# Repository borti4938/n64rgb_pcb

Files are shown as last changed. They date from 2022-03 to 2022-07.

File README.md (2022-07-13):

N64RGBv2.1 (PCB)
---

This repository contains all you need files to build your own DIY N64RGBv2.1 board.
Firmware is supplied in another repository.

Please don't ask me for selling a modding.
I either sell some prototypes on some forums marketplaces (which is very unlikely) or I don't have any of the boards.
This is a complete DIY modding project.
Everybody is on his own here.

**WARNING:**
This is an advanced DIY project if you do everything on your own. You need decent soldering skills.
The CPLD and the video DAC have 0.5mm fine pitched pins.
On the board there are some SMD1206 resistor and ferrite bead arrays.
However, there are some awesome shops out there selling the boards for a great price.

## Table of Contents

- [Checklist](https://github.com/borti4938/n64rgb_pcb#checklist-how-to-build-the-project)
- [Assembly](https://github.com/borti4938/n64rgb_pcb#assembly)
- [Installation](https://github.com/borti4938/n64rgb_pcb#installation)
  - [1. Open the Console](https://github.com/borti4938/n64rgb_pcb#1-open-the-console)
  - [2. Optional Steps](https://github.com/borti4938/n64rgb_pcb#2-optional-steps)
  - [3. Solder Work](https://github.com/borti4938/n64rgb_pcb#3-solder-work)
  - [4. Mount the N64 Advanced Modding PCB](https://github.com/borti4938/n64rgb_pcb#4-mount-the-n64-advanced-modding-pcb)
  - [5. Finish the Work](https://github.com/borti4938/n64rgb_pcb#5-finish-the-work)
- [Jumper Setup](https://github.com/borti4938/n64rgb_pcb#jumper-setup)
- [Cable Setup](https://github.com/borti4938/n64rgb_pcb#cable-setup)

## Checklist: How to build the project

- Use PCB files (either [KiCad-PCB design file](./n64rgbv2.1.kicad_pcb) or [Gerber files](./Gerber/)) to order your own PCB or simply use the [shared project(s) on OSHPark](https://oshpark.com/profiles/borti4938)
- If you paln to use solder paste, do not forget to order a stencil for top and bottom, too
- Source the components you need, e.g. from Mouser or Digikey.  
  The BOM is available in [here](./doc/BOM_n64rgbv2.1.xlsx).
- Wait for everything to arrive
- Assemble your PCB if you haven't use a PCBA service
- Set all jumpers
- Flash the firmware ([firmware releases](https://github.com/borti4938/n64rgb_fw/releases)) to the CPLD after installation (e.g. using an Altera USB Blaster)
  - Use the POF programming file named n64rgbv2\_1\__cpld-device_.pof
  - Using the intelFPGA programmer, JTAG chain is initialized by loading POF file
  - N64 needs to be powered for flashing
  - Power cycle the N64 after flashing
- If you want to go for a clean installation with custom made flexible PCBs, just visit the repository for add ons ([Flex PCB for the digital video interface](https://github.com/borti4938/n64rgb_project_misc/RCP2N64RGB), [Flex PCB for the analog video output](https://github.com/borti4938/n64rgb_project_misc/N64RGB2MoutFilter)

## Assembly

If you have all components available, you can start assembly your board.
The documentation provides assembly sheets ([top](./doc/n64rgb2.1_assembly_sheet_top.pdf) and [bottom](./doc/1_assembly_sheet_bot.pdf), which you can print out.
Together with the [BOM](./doc/BOM_n64rgbv2.1.xlsx) it is just a matter of time and effort to assembly everything.
Alternatively you can also use the [interactive BOM](./doc/ibom.html).

Please note that the assembly (and component sourcing) depends on which kind of CPLD family you use.
Supported are Max II and Max V CLPDs.
- If you use a Max II CPLD, you must use FB3 and leave U4, C41 and C42 unpopulated.
- If you use a Max V CPLD, you must use U4, C41 and C42 and leave FB3 unpopulated.

If you populate J3, which is the JTAG connector, please short the pins such that they are flush at the bottom side.
This reduces the risk to short on of these pins with the heat sink (where the PCB will be mounted).

Using non-clean flux (rosin based) is obviously recommended.
Even though it is "non-clean" I recommend cleaning everything afterwards (just for the visual finish).

Please double check everything for shorts once you finished your work.
Very important is that the power supply trace do not short to GND.
- 3.3V against GND (e.g. at C1 and at C52)
- 1.8V against GND (e.g. at C42)
- 5V against GND (e.g. at C4)

## Installation

Note that installation pictures partially show the N64Advanced board.
Pad design and installation is equivalent.

### 1. Open the console

- Remove Jumper Pak / Expansion Pak
- Remove screws from bottom side of the console  
(needs a 4.5mm gamebit tool)
- Lift top housing
- remove inner screws as marked  
(very last consoles made the heat sink design changed slightly)
- pull out the mainboard
- remove heat sink and RF shield
- **Hint** Now you have the chance to clean up your N64 shell

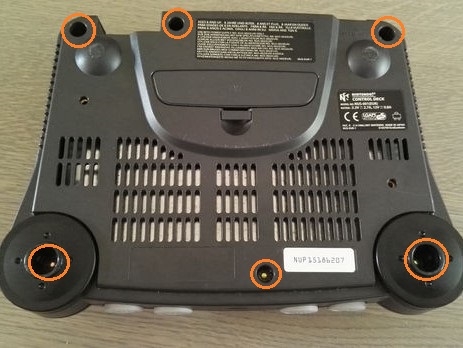
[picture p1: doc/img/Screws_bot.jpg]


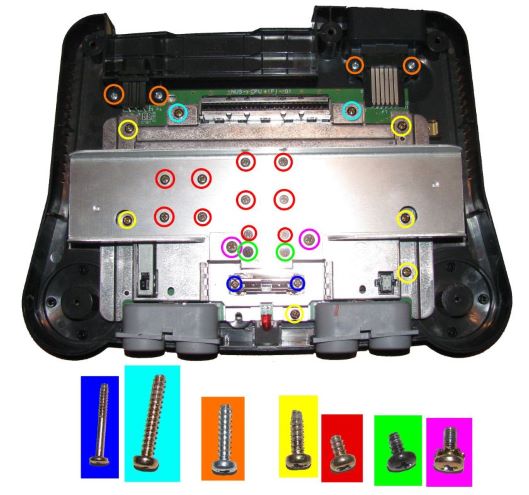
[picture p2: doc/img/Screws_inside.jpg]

(image by Zerberus (circuit-board.de user))

### 2. Optional Steps

#### 2.1 Preparation of Top RF Shield

This step is optional.
It helps a) to reduce mechanical stress on the flex cable (if used) and b) ensures maximal distance between digital signals (installation wires or flex cable) and analog signals (MultiOut).

- Locate the tap in the RF shield next to the cartridge slot at the side of the MultiOut.  
(this is the place where the installation wires / flex cable will be routed through)
- option 1: bend the tap away

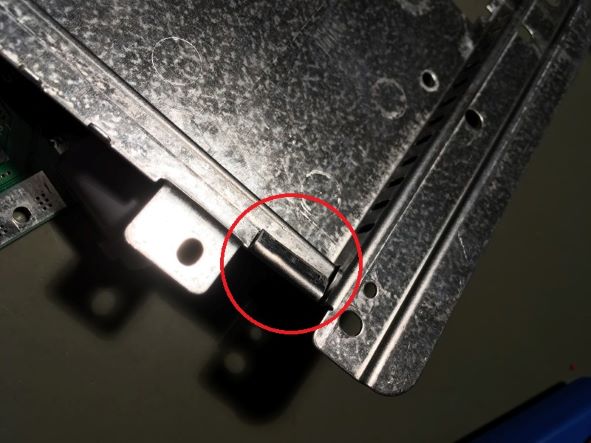
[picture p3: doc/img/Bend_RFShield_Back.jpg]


- option 2: simply cut the tab incl. the small piece up to the step in the RF shield

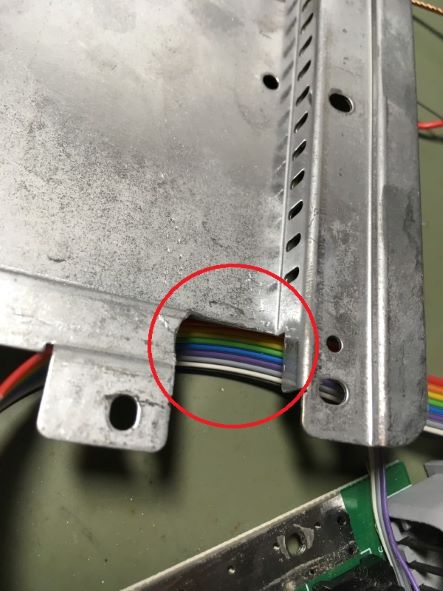
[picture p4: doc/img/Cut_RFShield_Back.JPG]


##### Some explanation on this optional step

Later, the data lines as well as the clock will be routed close to the MultiOut.
The distance between both is a crucial issue as your wires act as interferer.
Hence, having the tap bended might be ok, but it is better to cut some piece of the RF shield away to further increase the distance between MultiOut and data lines

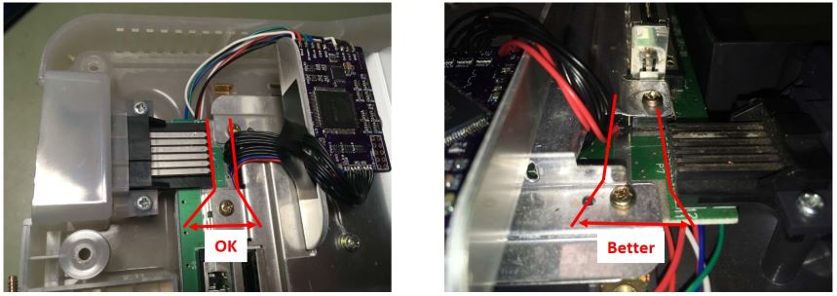
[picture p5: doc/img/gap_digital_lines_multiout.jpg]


#### GND insulation on the MultiOut

To have a better return path for the digital video lines defined, you may insulate GND from the MultiOut.
This step is only recommended if you have a noisy picture.
It comes with the drawback that a) you have a lot of more effort during installation and b) having a longer return path for the analog audio output as well as for S-Video and Composite Video as GND is later routed over the modding board.

- de-solder the MultiOut connector
- drill out the GND pads
- insulare the drills (e.g. with varnish (flex cable or wire install) or small shrink tubes (only wire installation))
- solder MultiOut back into place

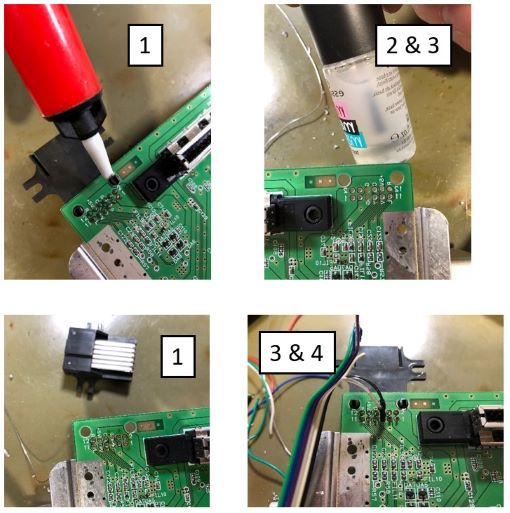
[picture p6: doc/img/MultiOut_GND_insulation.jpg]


### 3. Solder Work

You have the options to either install everything with casual installation wires or using flex cables.
This is just a trade-off between personal installation effort and price.
Personally, I recommend using the flex cable.

Sections 3.1 and 3.2 assume that you want to use the controller functions, so controller 1 will be connected.
However, this is optional, yet at the flex install the controller pad of the flex cable must not be left open!
Please also note section 3.3, where the installation of mechanical switches is described.

#### 3.1 Using the Flex Cable 

To use this option, you have to have the flex cables as shown at hand.
Note that the picture shows older prototype version.

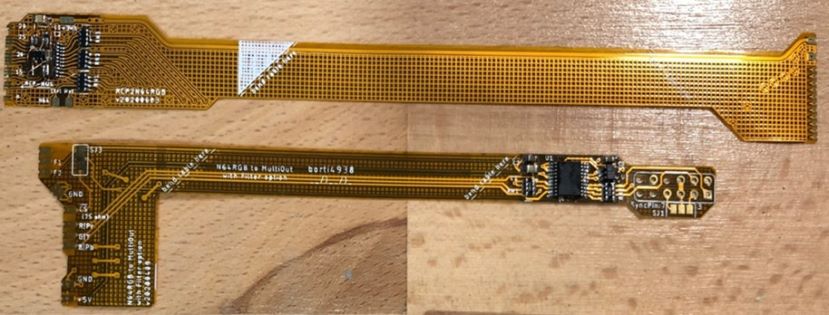
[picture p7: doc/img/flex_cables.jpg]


##### 3.1.1 Digital inputs

Start with the digital side:
- Solder the RCP connector side to the RCP-NUS as shown
  - first pin bottom – 8
  - last pin to – 28
- Connect 3.3V to the flex, e.g. taken from C141
- Connect Ctrl. and reset
  - reset from PIF-NUS pin 27
  - Controller from PIF-NUS pin 16  
  (Make sure that PIF-NUS pin 16 is connected to the middle pin of controller port 1, otherwise search for a suitable connection point)
- bend the flex as marked in a way such that you do not see the shaded area anymore.  
The flex will be routed over the MultiOut.

**Note**: when using the flex of version earlier than _v2022xxyy_ you need to cut the RF shield near the MultiOut as shown in 2.1

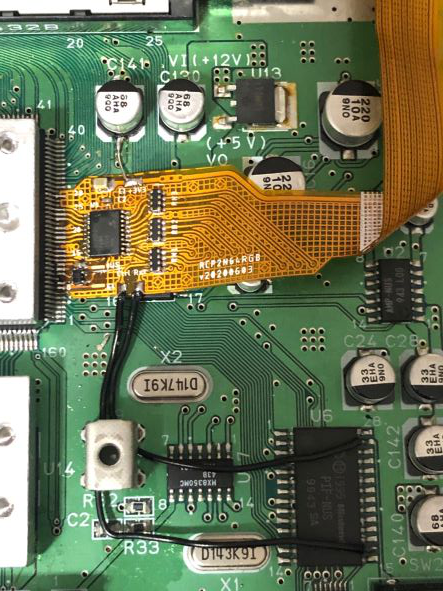
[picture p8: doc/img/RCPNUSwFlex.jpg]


##### 3.1.2 Analog outputs

Next up is the analog video flex which will be connected to the MultiOut.
Before you start here, make yourself clear where you want to route sync to.
This depends on whether you want to use sync on luma or sync on composite sync (raw sync) cable.

- Free the sync pin from the MultiOut, which means that you must trace back the copper track from the MultiOut pin and make sure that there is nothing connected to.
  - pin 3 (raw sync cable): usually unconnected. Only connected in earlier NTSC console (-CPU-01 to -CPU-03)
  - pin 7 (luma sync cable): usually connected. Search for a nearby resistor or trace back to the DENC-NUS or MAV-NUS and lift the luma pin. Remove the resistor or lift the pin at the DENC-NUS or MAV-NUS.
- solder the flex on its place of the MultiOut
- close **SJ1** on the flex from
  - middle to 3 if using raw sync
  - middle to 7 if using luma sync
- Note that it is also possible to connect sync pin 9 if you want to use a sync on composite video cable.
  - disconnect composite vide from pin 9 using the back tracing technique
  - solder a small wire from **SJ1** middle pad to pin 9 of the MultiOut

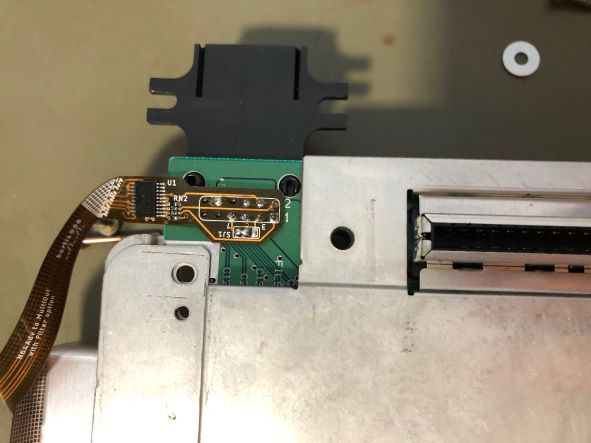
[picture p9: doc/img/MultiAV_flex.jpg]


#### 3.2 Using Wires

First you need to work out the digital video signals as well as reset and controller 1. 
Most of the signals needed has to be taken from video processor output; the RCP-NUS.
Next to the RCP-NUS is the video encoder, where several types are used during the variety of N64 designs.
The pinouts are given below.
Basically, we need D0-D6, /DSYNC and /CLK (or VCLK or CLOCK) for the modding board.

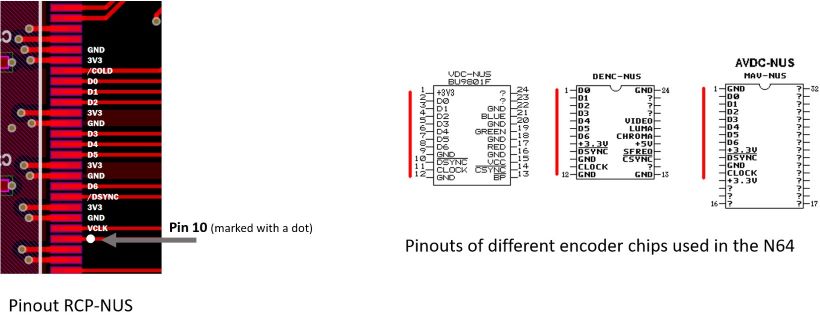
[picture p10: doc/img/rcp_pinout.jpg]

(RCP-NUS picture by Marshall; Encoder picture by Viletim)

Next to the video signals, you will need to get power (3.3V and GND), reset and controller 1.
This means you need in total 13 wires.
If you use a ribbon cable, I recommend you to use either a 15 conductor cable (double 3.3V and GND) or a 11 conductor cable and separate 3.3V and GND wires. 

- Locate the video encoder
  - Solder a bunch of wires to the video signal pins D0-D6, /DSYNC and /CLK
- Solder wires for reset and controller 1
  - reset from PIF-NUS pin 27
  - Controller from PIF-NUS pin 16  
  (Make sure that PIF-NUS pin 16 is connected to the middle pin of controller port 1, otherwise search for a suitable connection point)
- Solder two additional wires for 3.3V (can be picked off C141) and one for GND (large GND plane)
- Route all wires to the MultiOut port

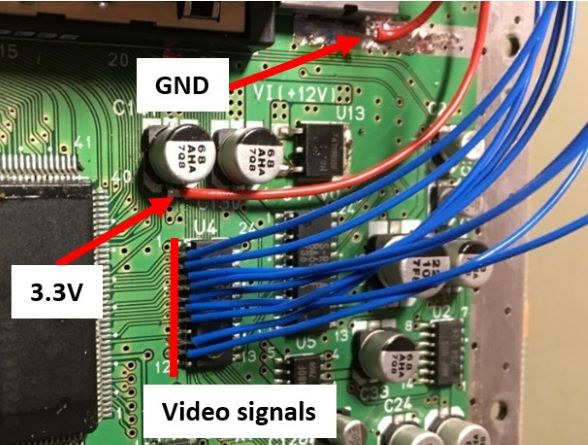
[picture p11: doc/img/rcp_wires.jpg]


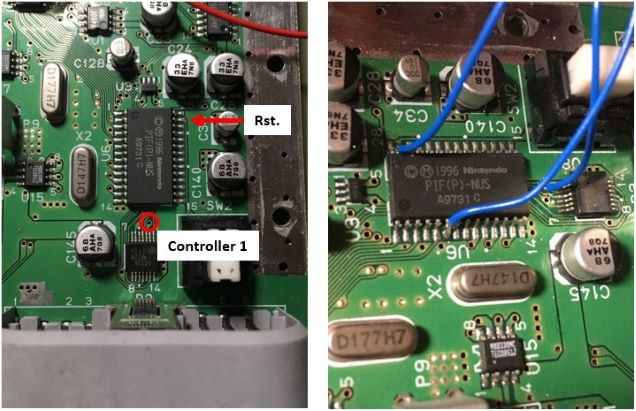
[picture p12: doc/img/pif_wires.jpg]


Next you can prepare wires for the analog video.
Connect several wires to the MultiOut.
Before you start here, make yourself clear where you want to route sync to.
This depends on whether you want to use a sync on composite video, a sync on luma or a sync on composite sync (raw sync) cable.

- Free the sync pin from the MultiOut, which means that you have to trace back the copper track from the MultiOut pin and make sure that there is nothing connected to.
  - pin 3 (raw sync cable): usually unconnected. Only connected in earlier NTSC console (-CPU-01 to -CPU-03)
  - pin 7 (luma sync cable): usually connected. Search for a nearby resistor or trace back to the DENC-NUS or MAV-NUS and lift the luma pin. Remove the resistor or lift the pin at the DENC-NUS or MAV-NUS.
  - pin 9 (composite video sync cable): usually connected. Search for a nearby resistor or trace back to the DENC-NUS or MAV-NUS and lift the luma pin. Remove the resistor or lift the pin at the DENC-NUS or MAV-NUS.
- Prepare some wires to the following pins
  - pin 1: red
  - pin 2: green
  - pin 4: blue
  - pin 3, 7 or 9: sync
  - pin 5 and/or 6: GND (connect pin 5 **and** pin 6 if you insulated GND from the MultiOut)
  - pin 10: 5V

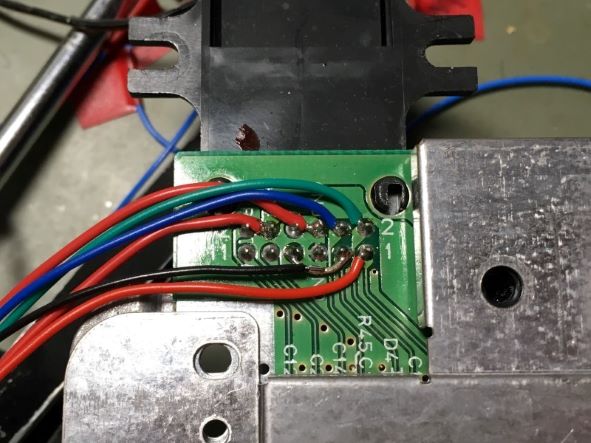
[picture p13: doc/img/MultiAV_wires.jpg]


You have the option to use the [Filter AddOn board](https://github.com/borti4938/n64rgb_project_misc/tree/master/FilterAddOn) here.
Note that the filter is optionally included in on the flex cable setup.

If you use the filter board, you clearly have to solder the filter board first and connect the wire to the pads of the filter board as marked on the silk screen.

#### 3.3 Mechanical switch

You can install mechanical switches to toggle VI-DeBlur on and off and also 16bit mode on and off.
At least I recommend installing a mechanical switch for the VI-DeBlur function.

Source a on/on or on/off switch like [this one](https://etim.net.au/shop/shop.php?crn=209&rn=559&action=show_detail).
If you source the switch as linked you can use [this 3D mount](https://www.thingiverse.com/thing:4584239) for a clean installation.

Connect the switch to J11.1 (VI-DeBlur) and/or to J11.2 (16bit mode) in a way such that the switch leaves the jumper open in one position and closes it at the other position.

### 4. Mount the N64 Advanced Modding PCB

The PCB is designed to fit on the heat sink of the N64.
There is a large via on the PCB where a M3 screw passes through.
Mount the PCB using a M3 screw of length 10mm or 12mm, a set of washers and a nut.
Be careful with the JTAG connector **J3** and ensure that the pins do not short to the heatsink!

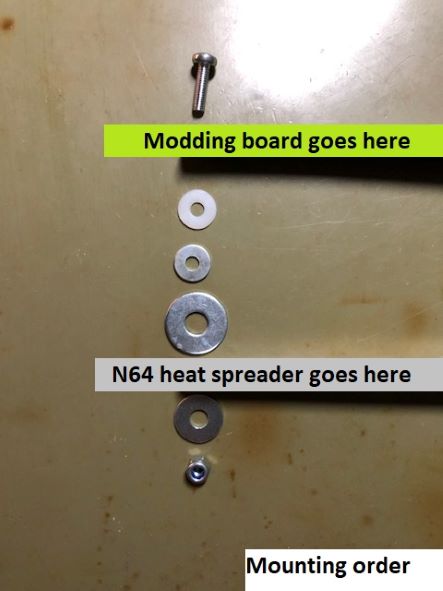
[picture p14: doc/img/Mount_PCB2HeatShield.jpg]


If you want to use the heat sink shield as an additional secure GND connection, you can also apply some solder to the mounting via.

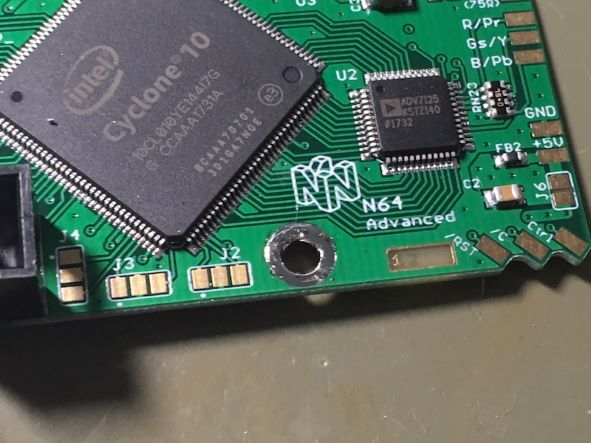
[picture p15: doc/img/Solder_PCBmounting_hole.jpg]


If everything is mounted and secured, the PCB should sit like that.

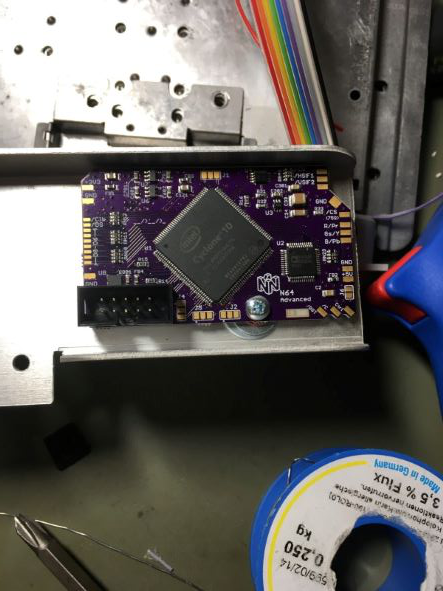
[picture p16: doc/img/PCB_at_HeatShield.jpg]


### 5. Finish the Work

Before continuing you can assemble the RF shield and heat sink back to the N64 mainboard.
In that way everything is secured in place where it belongs to.
Of course, if you use an installation with wires, make sure that you know which wire is for what.
On my ealrier installs I used some wire marker.

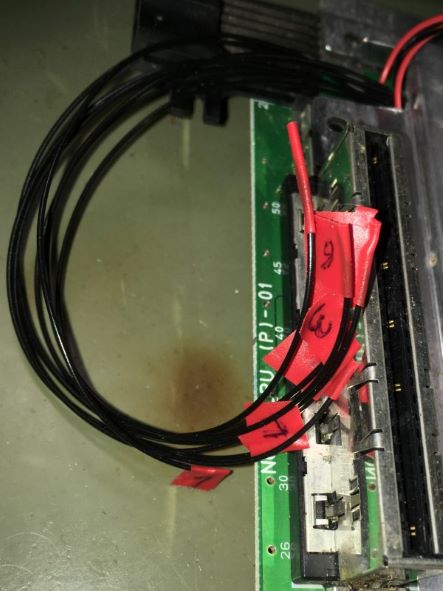
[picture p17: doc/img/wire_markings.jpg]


#### 5.1 With Flex Cable

Bend the flex cables gently at the shaded areas.
In that way you should be able to allign both flex cables at the N64RGBv2.1 modding board.
Solder the flex cables at their places.
(Please note subsection 5.3 - CSYNC).

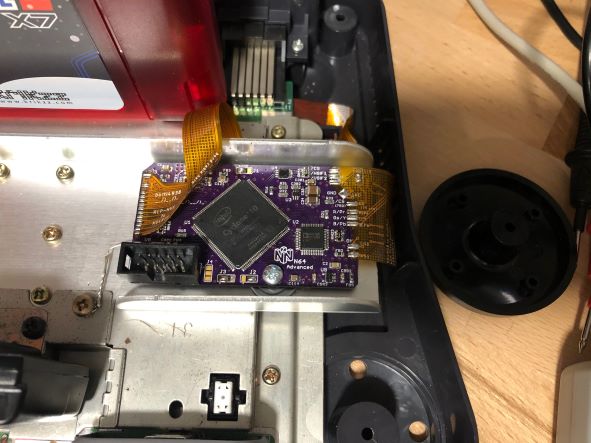
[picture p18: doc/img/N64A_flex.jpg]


Connect an extra GND wire as shown in 5.3.

#### 5.2 With Wires

Just connect every wire at its place.
The silk screen shows you where everything goes to.
(Please note subsection 5.3 - CSYNC).
Note that the picture shows an older version of the N64 Advanced.
Newer versions have reset and controller at the left-hand side.

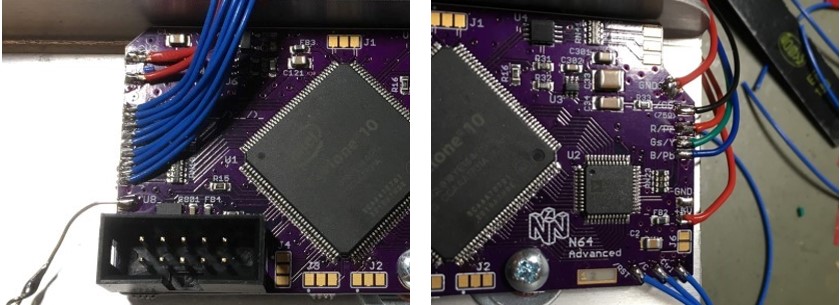
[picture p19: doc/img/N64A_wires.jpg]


Connect an extra GND wire as shown in 5.4.

#### 5.3 CSYNC

You have the option to connect _/CS_ or _/CS (75ohm)_.
I recommend using _/CS (75ohm)_ except if you have a true TTL sink, which is usually not the case!
In virtually 99% of all setups connecting the sync wire to _/CS (75ohm)_ is the way to go.

On installations with the flex cables follows that you must close SJ3 bottom on the flex.
Please note the Jumper Setup section to correctly setup the sync level.

#### 5.4 Extra GND Wire

Connect an extra GND wire to the heat sink screw.
This improves return path properties of the digital video lines.

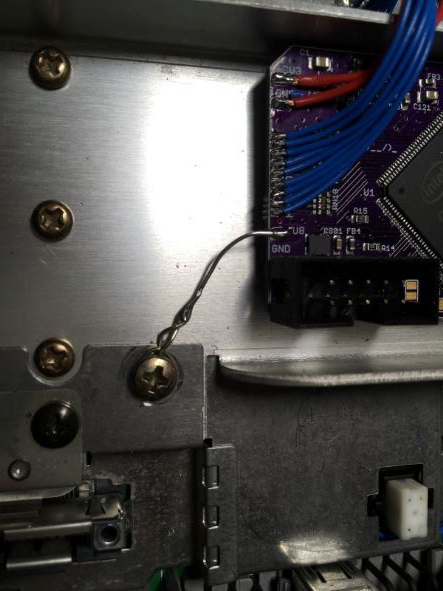
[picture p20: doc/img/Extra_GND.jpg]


## Jumper Setup

Jumpers with three pads have _J1#.1_ and _J1#.2_, where .1 is marked with an _arrow_.
Closing either jumper means that a short to the middle pad is needed.

#### J11 (VI-DeBlur and 16bit mode)

This jumper can act as a power cycle default.
You can also switch the state of the jumper using a mechanical switch to toggle the functions during runtime.

##### J11.1 
- opened: VI-DeBlur off
- closed: VI-DeBlur on

##### J11.2
- opened: 16bit mode off
- closed: 16bit mode on

#### J12 (IGR function control)
##### J12.1 (VI-DeBlur and 16bit mode)
- opened: controller functions for toggle VI-DeBlur and 16bit mode on/off are enabled
- closed: controller functions are disabled

##### J12.2 (in game reset)
- opened: reset by controller enabled
- closed: reset by controller disabled

#### J2 (Filter setup)
Needs filter add on to be installed.

- opened: use low pass filter
- closed: bypass filter

#### J21 (Sync on Green)
- open: SoG disabled
- closed: SoG enabled

#### J31 (CSYNC level @ _/CS (75ohm)_ pad)

- opened: appr. 1.87V @ 75ohm termination, i.e. needs a resistor inside the sync wire further attenuating the signal. Designed to work for cables with 470 ohm resistor inside resulting in appr. 450mV @ 75ohm termination
- closed: appr. 300mV @ 75ohm termination suitable for pass through wired cables at sync, works with standard TV / scaler setup

#### J3
_J3_ is the JTAG connector.

## Cable Setup

| Signal | Pin MultiOut | Pin SCART | Ref. GND in SCART | Cinch Plug | Note |
|:---|:---|:---|:---|:---|:-----|
| Red / Pr | 1 | 15 | 13 | Red plug | Using a 220uF cap in series is possible, yet not required |
| Green / Y | 2 | 11 | 9 | Green plug | Using a 220uF cap in series is possible, yet not required |
| Blue / Pb | 4 | 7 | 5 | Blue plug | Using a 220uF cap in series is possible, yet not required |
| Sync | 3, 7 or 9 | 20 | 17 | _not needed_ | Pin: See installation, Cable: see notes below |
| GND | 5, 6 | 4,5,9,13,17,18,21 | | Outer ring of each plug | Pin 21 @ SCART: outer shield |
| +5V | 10 | 16 | 18 | _not needed_ | SCART: use a 180ohm resistor in series |
| Audio left | 11 | 6 | 4 | Red plug | |
| Audio right | 12 | 2 | 4 | White plug | |

#### Notes on Sync:

- I recommend using the 75ohm compatible csync output.  
  You have a modding board with J31, you can select with J31 whether
  - you have a series resistor in you cable (J31 open) or
  - if you have a straightly wired sync connection (J31 closed).
- If you use TTL sync output, you have to add an additional resistor in series in every case if you want to use the cable on a non-TTL setup (0ohm to 900ohm) to attenuate the signal for  sinks with 75ohm.

#### RGB cables:

- If you buy an RGB cable, buy a typical RGB cable for a NTSC SNES with sync on luma (MultiAV pin 7) or sync on csync (MultiAV pin 3).
- If you bought a raw csync cable and if you use the 75ohm output, please ensure to set J31 correctly
  
#### PAL RGB cables (SNES PAL):

- PAL RGB cable, i.e. a cable with additional 75ohm resistors to GND, are not supported out of the box.
- You can support them if and only if you have the _Filter AddOn_.  
  To support the cable, replace RN2 with a 39ohm resistor array or solder a second 75ohm resistor array on top of the existing one.

#### RGsB Cables (Cinch):

With the given table you should be able to build your own component cable (passing RGB) or to build an adapter (see pictures below)
Unfortunately, there are no cables / adapter to buy.
Only chance is to buy a Wii component cable and use a MultiOut adapter (SNES/N64/GC style to Wii style).

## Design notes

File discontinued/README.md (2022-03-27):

### Jumpers N64RGBv1

- J11.1 -> activates 15bit color mode if closed.  **[1]**
- J11.2 -> activates VI-deblur if closed. **[1]**
  - J11.x are just pins on older versions. J11.1 is pin 91 (short to pin 90 to close jumper) and J11.2 is pin 2 (short to pin 1 to close jumper) **[2]**
- Pin 36 -> disables IGR functions toggle deblur and 15bit mode if shorted to pin 37 **[2]**
- J12 -> disables IGR function reset by controller
  - is just pin 66 on older v1 boards without a jumper - short to pin 67 to close jumper **[2]**
- Pad _FIL_ -> einables SD filter from THS7374 if open and disables filter if shorted to GND
  - on older boards it is pin 85 (unfortunately there is no GND pin next to it, so you have to short it with a wire to GND if you need to disable the SD filter)

### Jumpers N64RGBv2

- J11.1 -> activates 15bit color mode if closed.  **[1]**
- J11.2 -> activates VI-deblur if closed. **[1]**
- J12.x -> disables IGR functions if closed
  - x.1: VI-DeBlur and 15bit mode toggle by controller
  - x.2: reset by controller
- J21 -> enables Sync on Green if closed

### Notes  

All pins referring to pins of the CPLD (U1).

**[1]**  
Jumper becomes active on power cycle or if toggled while running operation.  

**[2]**
These are 'hidden jumper', which means it is just a pin where the neighbored pin is GND.

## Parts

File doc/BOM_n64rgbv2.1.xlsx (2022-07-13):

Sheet: MaxV Setup
Number of PCBs |  | 3
Designator | MPN | QTY/PCB | QTY | DESCRIPTION | VALUE | PACKAGE | NOTES
ICs and Regulators
U1 | 5M570ZT100C5N | 1 | 3 | CPLD with 570LEs |  | TQFP100
 | 5M240ZT100C5N |  |  | CPLD with 240LEs |  | TQFP100 | Alternative to 5M570ZT100 with less LEs, leave J1 open
U2 | ADV7125KSTZ50 | 1 | 3 | Video DAC 8bit, 3Ch. |  | 48-LQFP | can be replaced with ADV7123KSTZ50 on demand
U3 | TSH122ICT | 1 | 3 | Video buffer |  | SC-70-6
U4 | TLV70018DDCR | 1 | 3 | 1.8V LDO regulator |  | SOT-23-5
U5 | TLV70033DDCR | 1 | 3 | 3.3V LDO regulator |  | SOT-23-5
Power Supply Filtering
C1,C4 |  | 2 | 6 | Ceramic capacitor, X5R | 47uF / 6.3V | SMD0805
FB1,FB2,FB4,FB5 | BLM18PG471SN1D | 4 | 12 | Ferrit bead |  | SMD0603
Remaining passive components
C2,C3,C5,C6,C31 |  | 5 | 15 | Ceramic capacitor, X5R | 10uF / 6.3V | SMD0805
C10-C19,C20,C22,C24,C27,C28 |  | 15 | 45 | Ceramic capacitor, X7R | 0.1uF / 50V (10%) | SMD0603
C21,C23,C25,C32 |  | 4 | 12 | Ceramic capacitor, X7R | 0.01uF / 50V | SMD0603
C33 |  | 1 | 3 | Ceramic capacitor, X5R | 33uF / 6.3V | SMD0805
C34 |  | 1 | 3 | Ceramic capacitor, X5R | 22uF / 6.3V | SMD0805
C41,C42,C51,C52 |  | 4 | 12 | Ceramic capacitor, X5R | 1uF / 6.3V | SMD0603
R10 | CRCW06031K00FKTB | 1 | 3 | Resistor | 1kohm (1%) | SMD0603
R2,R11, R12 | CRCW0603-10K | 3 | 9 | Resistor | 10kohm (1%) | SMD0603
R13 | RC0603FR-07330RL | 1 | 3 | Resistor | 330ohm (1%) | SMD0603
R21 | RC0603FR-07523RL | 1 | 3 | Resistor | 518 | SMD0603 | with ADV7123: use 516ohm resistor; for PAL-Standard: 528ohm/527ohm
 |  |  |  |  |  |  | Value of MPN reference differs to ideal value to allow for negative margin!
R22,R31 | RC0603FR-074K7L | 2 | 6 | Resistor | 4.7kohm (1%) | SMD0603
R32 | RC0603FR-076K19L | 1 | 3 | Resistor | 6.19kohm (1%) | SMD0603
R33 | RC0603FR-07523RL | 1 | 3 | Resistor | 523 | SMD0603 | usually same as R21
R34 | RC0603FR-0775RL | 1 | 3 | Resistor | 75 | SMD0603
RN10,RN11,RN12 | CAT16-47R0F4LF / CAY16-47R0F4LF | 3 | 9 | Resistor Array (4x) | 47 | SMD1206 | Use this if you don't have resistors at the RCP output or if you use a flex with buffer Ics
 | BK32164M121-T |  |  | Ferrite Beads MULTILYR CHP | BD 120OHMS 25% | SMD1206 | Use this alternative if you have resistors at the RCP output, e.g. with the "old" flex cable adapter
RN23 | CAT16-75R0F4LF / CAY16-75R0F4LF |  | 1 | Resistor Array (4x) | 75 | SMD1206
J3 | 3020-10-0300-00 | 1 | 3 | SMD part |  |  | JTAG Connector
 | 30310-6002HB |  |  | THT part alternative |  |  | JTAG Connector
Unpopulated Footprints
FB3 | Don't use FB3 in MaxV setup!!! Otherwise you'll harm your CPLD at first power cycle
MPNs are only suggestions! You can use equivalent components, too.

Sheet: MaxII Setup
Number of PCBs |  | 3
Designator | MPN | QTY/PCB | QTY | DESCRIPTION | VALUE | PACKAGE | NOTES
ICs and Regulators
U1 | EPM570T100C5N | 1 | 1 | CPLD with 570LEs |  | TQFP100
 | EPM240T100C5N |  |  | CPLD with 240LEs |  | TQFP100 | Alternative to EPM570T100C5N with less LEs
U2 | ADV7125KSTZ50 | 1 | 3 | Video DAC 8bit, 3Ch. |  | 48-LQFP | can be replaced with ADV7123KSTZ50 on demand
U3 | TSH122ICT | 1 | 3 | Video buffer |  | SC-70-6
U5 | TLV70033DDCR | 1 | 3 | 3.3V LDO regulator |  | SOT-23-5
Power Supply Filtering
C1,C4 |  | 2 | 6 | Ceramic capacitor, X5R | 47uF / 6.3V | SMD0805
FB1,FB2,FB3,FB4,FB5 | BLM18PG471SN1D | 5 | 15 | Ferrit bead |  | SMD0603
Remaining passive components
C2,C3,C5,C6,C31 |  | 5 | 15 | Ceramic capacitor, X5R | 10uF / 6.3V | SMD0805
C10-C19,C20,C22,C24,C27,C28 |  | 15 | 45 | Ceramic capacitor, X7R | 0.1uF / 50V (10%) | SMD0603
C21,C23,C25,C32 |  | 4 | 12 | Ceramic capacitor, X7R | 0.01uF / 50V | SMD0603
C33 |  | 1 | 3 | Ceramic capacitor, X5R | 33uF / 6.3V | SMD0805
C34 |  | 1 | 3 | Ceramic capacitor, X5R | 22uF / 6.3V | SMD0805
C51,C52 |  | 2 | 6 | Ceramic capacitor, X5R | 1uF / 6.3V | SMD0603
R10 | CRCW06031K00FKTB | 1 | 3 | Resistor | 1kohm (1%) | SMD0603
R2,R11, R12 | CRCW0603-10K | 3 | 9 | Resistor | 10kohm (1%) | SMD0603
R13 | RC0603FR-07330RL | 1 | 3 | Resistor | 330ohm (1%) | SMD0603
R21 | RC0603FR-07523RL | 1 | 3 | Resistor | 518 | SMD0603 | with ADV7123: use 516ohm resistor; for PAL-Standard: 528ohm/527ohm
 |  |  |  |  |  |  | Value of MPN reference differs to ideal value to allow for negative margin!
R22,R31 | RC0603FR-074K7L | 2 | 6 | Resistor | 4.7kohm (1%) | SMD0603
R32 | RC0603FR-076K19L | 1 | 3 | Resistor | 6.19kohm (1%) | SMD0603
R33 | RC0603FR-07523RL | 1 | 3 | Resistor | 523 | SMD0603 | usually same as R21
R34 | RC0603FR-0775RL | 1 | 3 | Resistor | 75 | SMD0603
RN10,RN11,RN12 | CAT16-47R0F4LF / CAY16-47R0F4LF | 3 | 9 | Resistor Array (4x) | 47 | SMD1206 | Use this if you don't have resistors at the RCP output or if you use a flex with buffer Ics
 | BK32164M121-T |  |  | Ferrite Beads MULTILYR CHP | BD 120OHMS 25% | SMD1206 | Use this alternative if you have resistors at the RCP output, e.g. with the "old" flex cable adapter
RN23 | CAT16-75R0F4LF / CAY16-75R0F4LF |  | 1 | Resistor Array (4x) | 75 | SMD1206
J3 | 3020-10-0300-00 | 1 | 3 | SMD part |  |  | JTAG Connector
 | 30310-6002HB |  |  | THT part alternative |  |  | JTAG Connector
Unpopulated Footprints
U4,C41,C42
MPNs are only suggestions! You can use equivalent components, too.

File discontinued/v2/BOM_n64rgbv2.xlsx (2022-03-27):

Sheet: MaxV Setup
Designator | MPN | QTY | DESCRIPTION | VALUE | PACKAGE | NOTES
ICs and Regulators
U1 | 5M240ZT100C5N | 1 | CPLD with 240LEs |  | TQFP100 | Recommended part, leave J1 open, Alternative part: 5M240ZT100C4N
 | 5M570ZT100C5N |  | CPLD with 570LEs |  | TQFP100 | Alternative to 5M240ZT100 with more LEs, Close J1, Alternative part: 5M570ZT100C4N
U2 | ADV7125KSTZ50 | 1 | Video DAC 8bit, 3Ch. |  | 48-LQFP | can be replaced with ADV7123KSTZ50 on demand
U3 | TSH122ICT | 1 | Video buffer |  | SC-70-6
U4 | TLV70018DDCR | 1 | 1.8V LDO regulator |  | SOT-23-5
Power Supply Filtering
C1,C4 | GRM219R60J476ME44D | 2 | Ceramic capacitor, X5R | 47uF / 6.3V | SMD0805
FB1,FB2 | BLM18PG471SN1D | 2 | Ferrit bead |  | SMD0603
Remaining passive components
C2,C3,C5,C31 | GRM188R61E106KA73D | 4 | Ceramic capacitor, X5R | 10uF / 6.3V | SMD0805
C10-C19,C20,C22,C24,C27,C28 | GRM188R71H104KA93J | 15 | Ceramic capacitor, X7R | 0.1uF / 50V (10%) | SMD0603
C21,C23,C25,C32 | GRM188R70J103KA01D | 4 | Ceramic capacitor, X7R | 0.01uF / 50V | SMD0603
C33 | GRM32DR60J336ME19L | 1 | Ceramic capacitor, X5R | 33uF / 6.3V | SMD1210
C34 | GRM31CR60J226KE19L | 1 | Ceramic capacitor, X5R | 22uF / 6.3V | SMD1206
C41,C42 | GRM18R60J105KA01J | 2 | Ceramic capacitor, X5R | 1uF / 6.3V | SMD0603
R10 | CRCW06031K00FKTB | 1 | Resistor | 1kohm (1%) | SMD0603
R11, R12 | CRCW0603-10K | 2 | Resistor | 10kohm (1%) | SMD0603
R13 | RC0603FR-07330RL | 1 | Resistor | 330ohm (1%) | SMD0603
R21 | RC0603FR-07523RL | 1 | Resistor | 518 | SMD0603 | with ADV7123: use 516ohm resistor; for PAL-Standard: 528ohm/527ohm
 |  |  |  |  |  | Value of MPN reference differs to ideal value to allow for negative margin!
R22,R31 | RC0603FR-074K7L | 2 | Resistor | 4.7kohm (1%) | SMD0603
R32 | RC0603FR-07475RL | 1 | Resistor | 475ohm (1%) | SMD0603
R33 | RC0603FR-0775RL | 1 | Resistor | 75 | SMD0603
RN10,RN11,RN12 | BK32164M121-T | 3 | Ferrite Beads MULTILYR CHP | BD 120OHMS 25% | SMD1206 | Use this if you have resistors at the RCP output, i.e. the flex cable adapter
 | CAT16-47R0F4LF / CAY16-47R0F4LF |  | Resistor Array (4x) | 47 | SMD1206 | Only use this if you don't have resistors at the RCP output
RN23 | CAT16-75R0F4LF / CAY16-75R0F4LF | 1 | Resistor Array (4x) | 75 | SMD1206
J3 | 30310-6002HB | 1 |  |  |  | JTAG Connector
Unpopulated Footprints
FB3 | Don't use FB3 in MaxV setup!!! Otherwise you'll harm your CPLD at first power cycle
Flex Cable Adapter |  | More information under misc/RCP2Pads/README.md
RN1,RN2,RN3,RN4 | CAT16-47R0F4LF / CAY16-47R0F4LF | 4 | Resistor Array (4x) | 47 | SMD1206 | Not marked on silkscreen
MPNs are only suggestions! You can use equivalent components, too.

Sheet: MaxII Setup
Designator | MPN | QTY | DESCRIPTION | VALUE | PACKAGE | NOTES
ICs and Regulators
U1 | EPM570T100C5N | 1 | CPLD with 570LEs |  | TQFP100 | Close J1
 | EPM240T100C5N |  | CPLD with 240LEs |  | TQFP100 | Alternative to EPM570T100C5N with less Les, leave J1 open
U2 | ADV7125KSTZ50 | 1 | Video DAC 8bit, 3Ch. |  | 48-LQFP | can be replaced with ADV7123KSTZ50 on demand
U3 | TSH122ICT | 1 | Video buffer |  | SC-70-6
Power Supply Filtering
C1,C4 | GRM219R60J476ME44D | 2 | Ceramic capacitor, X5R | 47uF / 6.3V | SMD0805
FB1,FB2,FB3 | BLM18PG471SN1D | 3 | Ferrit bead |  | SMD0603
Remaining passive components
C2,C3,C5,C31 | GRM188R61E106KA73D | 4 | Ceramic capacitor, X5R | 10uF / 6.3V | SMD0805
C10-C19,C20,C22,C24,C27,C28 | GRM188R71H104KA93J | 15 | Ceramic capacitor, X7R | 0.1uF / 50V (10%) | SMD0603
C21,C23,C25,C32 | GRM188R70J103KA01D | 4 | Ceramic capacitor, X7R | 0.01uF / 50V | SMD0603
C33 | GRM32DR60J336ME19L | 1 | Ceramic capacitor, X5R | 33uF / 6.3V | SMD1210
C34 | GRM31CR60J226KE19L | 1 | Ceramic capacitor, X5R | 22uF / 6.3V | SMD1206
R10 | CRCW06031K00FKTB | 1 | Resistor | 1kohm (1%) | SMD0603
R11, R12 | CRCW0603-10K | 2 | Resistor | 10kohm (1%) | SMD0603
R13 | RC0603FR-07330RL | 1 | Resistor | 330ohm (1%) | SMD0603
R21 | RC0603FR-07523RL | 1 | Resistor | 518 | SMD0603 | with ADV7123: use 516ohm resistor; for PAL-Standard: 528ohm/527ohm
 |  |  |  |  |  | Value of MPN reference differs to ideal value to allow for negative margin!
R22,R31 | RC0603FR-074K7L | 2 | Resistor | 4.7kohm (1%) | SMD0603
R32 | RC0603FR-07475RL | 1 | Resistor | 475ohm (1%) | SMD0603
R33 | RC0603FR-0775RL | 1 | Resistor | 75 | SMD0603
RN10,RN11,RN12 | BK32164M121-T | 3 | Ferrite Beads MULTILYR CHP | BD 120OHMS 25% | SMD1206 | Use this if you have resistors at the RCP output, i.e. the flex cable adapter
 | CAT16-47R0F4LF / CAY16-47R0F4LF |  | Resistor Array (4x) | 47 | SMD1206 | Only use this if you don't have resistors at the RCP output
RN23 | CAT16-75R0F4LF / CAY16-75R0F4LF | 1 | Resistor Array (4x) | 75 | SMD1206
J3 | 30310-6002HB | 1 |  |  |  | JTAG Connector
Unpopulated Footprints
U4,C41,C42 | These components are for MaxV setup only!!! Leave them free.
Flex Cable Adapter |  | More information under misc/RCP2Pads/README.md
RN1,RN2,RN3,RN4 | CAT16-47R0F4LF / CAY16-47R0F4LF | 4 | Resistor Array (4x) | 47 | SMD1206 | Not marked on silkscreen
MPNs are only suggestions! You can use equivalent components, too.

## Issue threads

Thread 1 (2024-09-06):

CPLD Replacement

TheDrifter363, 2024-09-06:
Hey Borti,

I was interested in using your mod for my n64, but it looks like the altera and amd CPLDs you recommended are no longer in stock, they're obsolete. You think your firmware could work on any alternatives? Digikey recommended me this one by Microchip:

https://www.digikey.com/en/products/detail/microchip-technology/ATF1504ASV-15AU44/1008326

I'm not sure if your firmware is manufacturer specific though. Thought I'd ask. Thanks man.

borti4938, 2024-09-07:
The CPLD you picked is way to small to fit all functions. Actually the controller reading does not fit. If you want to go with just the basics (like on the [n64rgb_flex project](https://github.com/borti4938/n64rgb_flex), the CPLD is large enough, but I have bad experience with it; a long time ago I tried to get it to work reliably.

- My recommendation for this project: go with the MaxV CPLD setup. It is overall the cheaper option over the MaxII setup.
- For the [n64rgb_flex project](https://github.com/borti4938/n64rgb_flex) project: source CPLDs from chinese market or adapt everything to use a MaxV CPLD, e.g. using the 5M80ZE64C5N.

(I included some words on the n64rgb_flex project as I think you may mean this one. (manufacturer of CPLDs, CPLD size))

TheDrifter363, 2024-09-08:
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

Hey Borti thanks for responding!

Yeah I realized after I made this, I meant to post this issue on the flex page. Which I realize this isn't an issue at all, as I found a 44 pin TQFP that was compatible with your firmware.

Alright, so what I'm getting from your reply is to not use the flex pcb? Just stick with this standard n64rgb? I'm not looking for any HDMI or anything like that, just simple rgb, so this is why I was gravitating towards these pcbs.

What do you recommend, regular or flex?

borti4938, 2024-09-08:
Personally I only use the flex version if I build some. So I guess I recommend that one over this project.

For my next order (which is not planned yet), I will probably update the CPLD there.

Closed 2024-09-08.

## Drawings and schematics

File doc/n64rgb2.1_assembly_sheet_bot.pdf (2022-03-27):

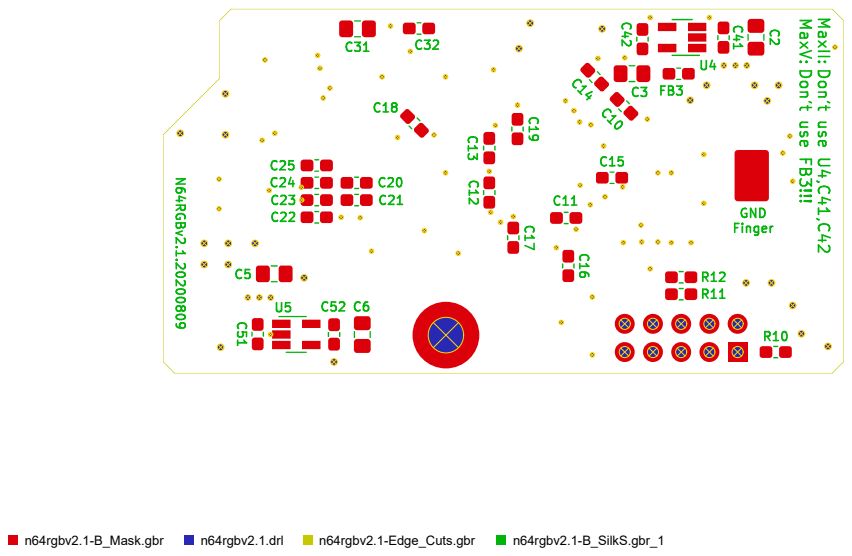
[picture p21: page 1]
n64rgbv2.1-B_Mask.gbr; n64rgbv2.1.drl; n64rgbv2.1-Edge_Cuts.gbr; n64rgbv2.1-B_SilkS.gbr_1

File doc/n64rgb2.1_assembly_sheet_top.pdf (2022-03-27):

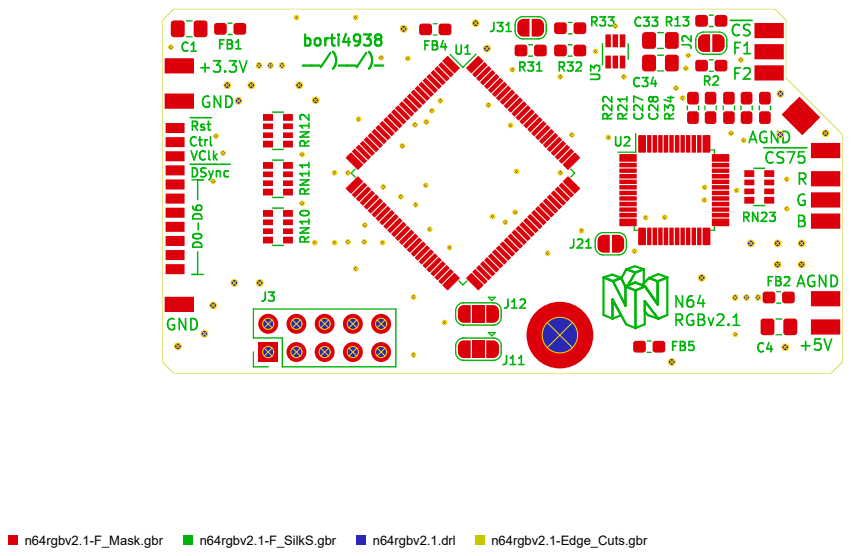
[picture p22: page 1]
n64rgbv2.1-F_Mask.gbr; n64rgbv2.1-F_SilkS.gbr; n64rgbv2.1.drl; n64rgbv2.1-Edge_Cuts.gbr

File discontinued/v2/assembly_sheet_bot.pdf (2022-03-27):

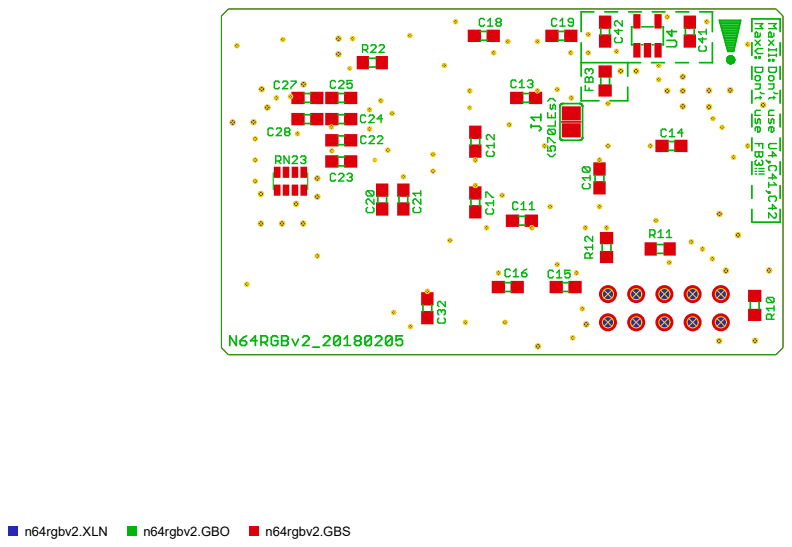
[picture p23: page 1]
n64rgbv2.XLN; n64rgbv2.GBO; n64rgbv2.GBS

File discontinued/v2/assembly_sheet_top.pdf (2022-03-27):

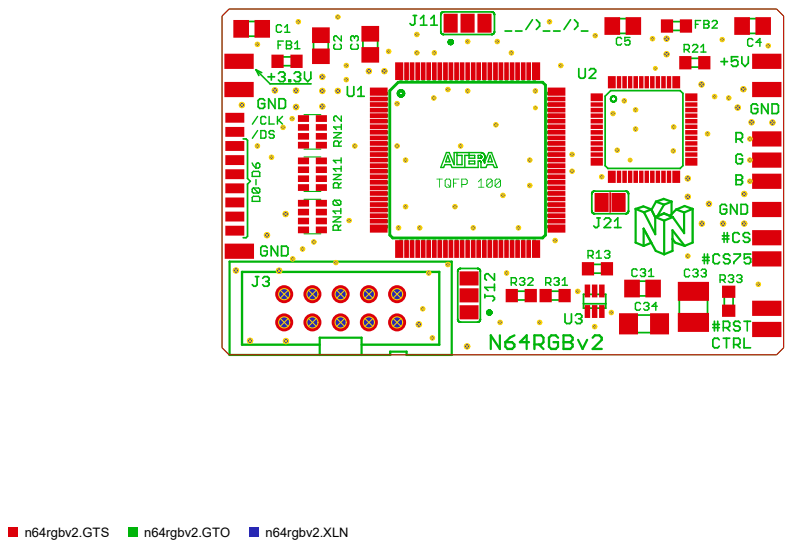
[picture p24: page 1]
n64rgbv2.GTS; n64rgbv2.GTO; n64rgbv2.XLN

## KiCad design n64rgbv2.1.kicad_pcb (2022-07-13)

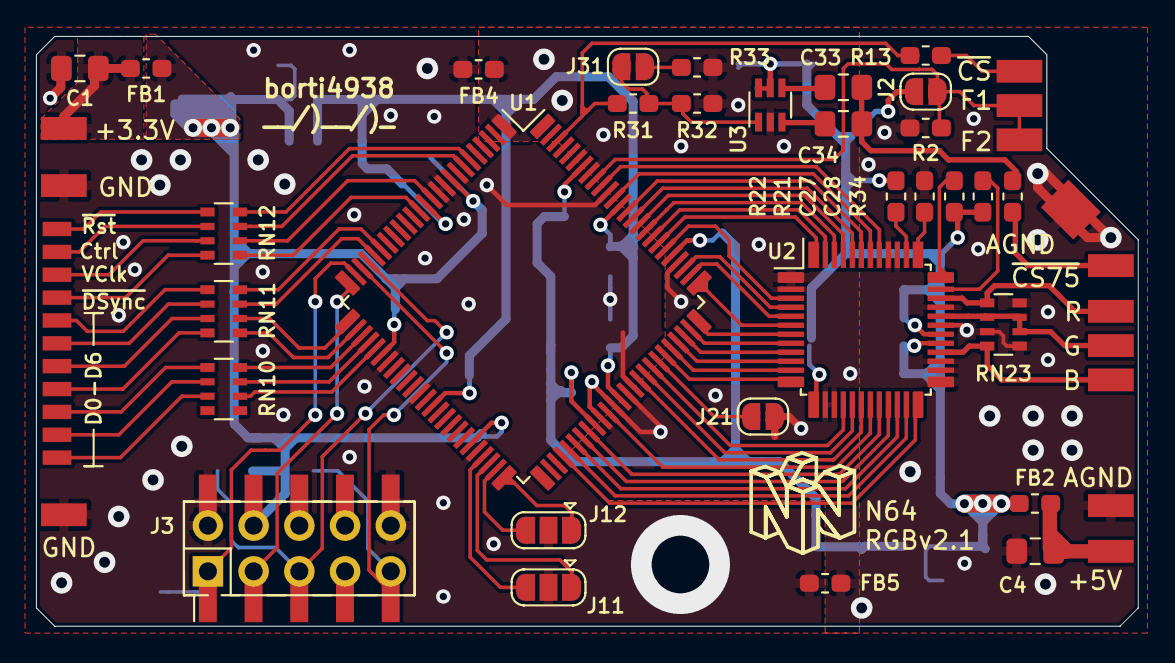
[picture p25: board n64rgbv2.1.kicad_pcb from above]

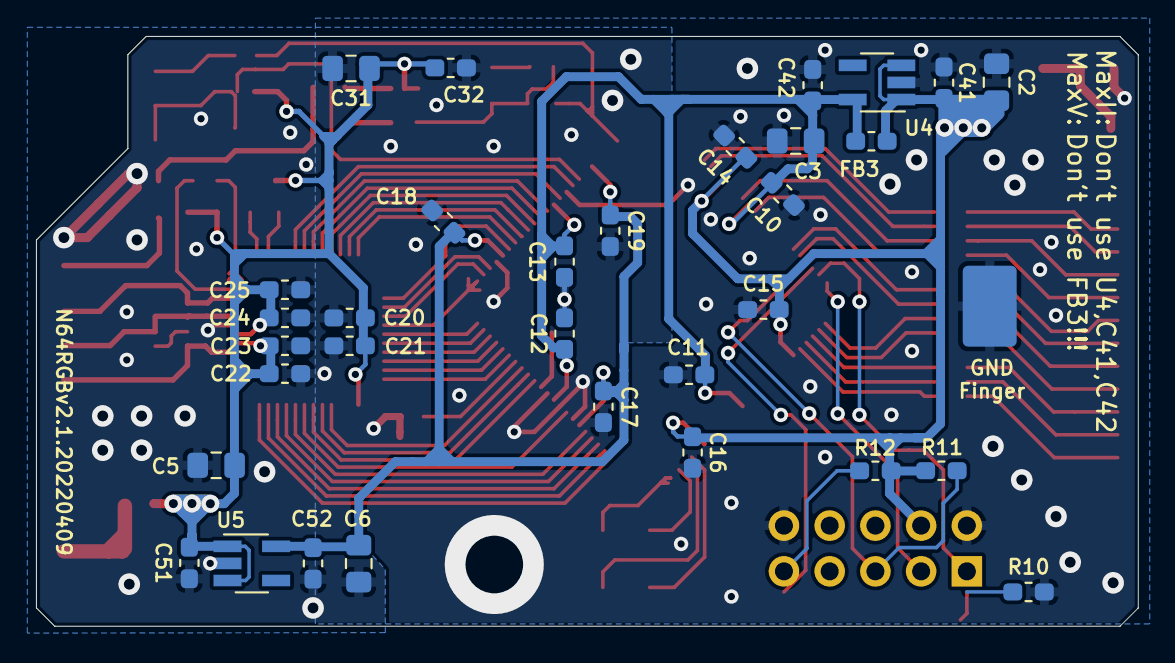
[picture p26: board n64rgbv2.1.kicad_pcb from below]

Board: 2 copper layers, 61.2 x 32.8 mm, 90 parts (33 on the bottom side), 82 nets.

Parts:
C1, C4: 47u; C_0805_2012Metric_Pad1.15x1.40mm_HandSolder
C2, C3, C5, C6, C31: 10u; C_0805_2012Metric_Pad1.15x1.40mm_HandSolder
C10, C11, C12, C13, C14, C15, C16, C17, C18, C19, C20, C22, C24, C27, C28: 0.1u; C_0603_1608Metric_Pad1.05x0.95mm_HandSolder
C21, C23, C25, C32: 0.01u; C_0603_1608Metric_Pad1.05x0.95mm_HandSolder
C33: 33u; C_0805_2012Metric_Pad1.15x1.40mm_HandSolder
C34: 22u; C_0805_2012Metric_Pad1.15x1.40mm_HandSolder
C41, C42, C51, C52: 1u; C_0603_1608Metric_Pad1.05x0.95mm_HandSolder
FB1, FB2, FB3, FB4, FB5: MPZ1608S221ATA00; R_0603_1608Metric_Pad1.05x0.95mm_HandSolder
J2, J21, J31: SolderJumper_2_Open; SolderJumper-2_P1.3mm_Open_RoundedPad1.0x1.5mm
J3: 30310-6002HB; PinHeader_2x05_P2.54mm_Vertical
J3b1: 30310-6002HB; PinHeader_2x05_P2.54mm_Vertical_SMD
J11, J12: SolderJumper_3_Open; SolderJumper-3_P1.3mm_Open_RoundedPad1.0x1.5mm
P_3V3, P_5V1: Conn_01x01; Wirepad_1.27_2.54
P_B1: Conn_01x01; Wirepad_1.27_2.54
P_CS1: Conn_01x01; Wirepad_1.27_2.54
P_CS_75: Conn_01x01; Wirepad_1.27_2.54
P_CTRL1: Conn_01x01; Wirepad_0.8_1.6
P_D0, P_D1, P_D2, P_D3, P_D4, P_D5, P_D6: Conn_01x01; Wirepad_0.8_1.6
P_DSYNC1: Conn_01x01; Wirepad_0.8_1.6
P_F1, P_F2: Conn_01x01; Wirepad_1.27_2.54
P_G1: Conn_01x01; Wirepad_1.27_2.54
P_GND_0, P_GND_1, P_GND_2, P_GND_3, P_GND_4: Conn_01x01; Wirepad_1.27_2.54
P_R1: Conn_01x01; Wirepad_1.27_2.54
P_RST1: Conn_01x01; Wirepad_0.8_1.6
P_VCLK1: Conn_01x01; Wirepad_0.8_1.6
R2, R11, R12: 10k; R_0603_1608Metric_Pad1.05x0.95mm_HandSolder
R10: 1k; R_0603_1608Metric_Pad1.05x0.95mm_HandSolder
R13: 330; R_0603_1608Metric_Pad1.05x0.95mm_HandSolder
R21: 518/515; R_0603_1608Metric_Pad1.05x0.95mm_HandSolder
R22, R31: 4k7; R_0603_1608Metric_Pad1.05x0.95mm_HandSolder
R32: 6k19; R_0603_1608Metric_Pad1.05x0.95mm_HandSolder
R33: 523; R_0603_1608Metric_Pad1.05x0.95mm_HandSolder
R34: 75; R_0603_1608Metric_Pad1.05x0.95mm_HandSolder
RN10, RN11, RN12: CAT16-47R0F4LF / CAY16-47R0F4LF; R_Array_Convex_4x0603
RN23: CAY16-75R0F4LF; R_Array_Convex_4x0603
SHIELD_FINGER1: S1761-42R; Pad_4.5_3.0
U1: EPM570T100; TQFP-100_14x14mm_P0.5mm
U2: ADV7125; LQFP-48_7x7mm_P0.5mm
U3: TSH122ICT; SC-70-6
U4: TLV70018_SOT23-5; SOT-23-5_HandSoldering
U5: TLV70033_SOT23-5; SOT-23-5_HandSoldering

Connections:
+1V8: C3.1, C10.1, C11.1, C12.1, C13.1, C42.1, FB3.1, U1.13 (VCCINT), U1.39 (VCCINT), U1.63 (VCCINT), U1.88 (VCCINT), U4.5 (OUT)
+3.3VADC: C2.1, C14.1, C15.1, C16.1, C41.1, FB1.1, FB3.2, J3.4, J3b1.4, R11.1, R12.1, U1.9 (VCCIO1), U1.31 (VCCIO1), U1.45 (VCCIO1), U4.1 (IN), U4.3 (EN)
+3V3: C6.1, C17.1, C18.1, C19.1, C52.1, U1.59 (VCCIO2), U1.80 (VCCIO2), U1.94 (VCCIO2), U5.5 (OUT)
+5VA: C5.1, C20.1, C21.1, C22.1, C23.1, C24.1, C25.1, C27.2, C28.2, C31.1, C32.1, C51.1, FB2.1, J2.1 (A), R22.1, U2.13 (VAA), U2.29 (VAA), U2.30 (VAA), U3.5 (EN), U3.6 (Vcc), U5.1 (IN), U5.3 (EN)
/B0: U1.68 (IO2_68), U2.16 (B0)
/B1: U1.67 (IO2_67), U2.17 (B1)
/B2: U1.66 (IO2_66), U2.18 (B2)
/B3: U1.61 (IO2_61), U2.19 (B3)
/B4: U1.58 (IO2_58), U2.20 (B4)
/B5: U1.57 (IO2_57), U2.21 (B5)
/B6: U1.56 (IO2_56), U2.22 (B6)
/B7: U1.55 (IO2_55), U2.23 (B7)
/CTRL_cpld: RN12.7 (R2.2), U1.7 (IO1_7)
/D0_cpld: RN10.6 (R3.2), U1.30 (IO1_30)
/D1_cpld: RN10.7 (R2.2), U1.29 (IO1_29)
/D2_cpld: RN10.8 (R1.2), U1.28 (IO1_28)
/D3_cpld: RN11.5 (R4.2), U1.27 (IO1_27)
/D4_cpld: RN11.6 (R3.2), U1.26 (IO1_26)
/D5_cpld: RN11.7 (R2.2), U1.21 (IO1_21)
/D6_cpld: RN11.8 (R1.2), U1.20 (IO1_20)
/DSYNC_cpld: RN12.5 (R4.2), U1.14 (IO1_14/GCLK1)
/G0: U1.81 (IO2_81), U2.3 (G0)
/G1: U1.78 (IO2_78), U2.4 (G1)
/G2: U1.77 (IO2_77), U2.5 (G2)
/G3: U1.76 (IO2_76), U2.6 (G3)
/G4: U1.75 (IO2_75), U2.7 (G4)
/G5: U1.74 (IO2_74), U2.8 (G5)
/G6: U1.73 (IO2_73), U2.9 (G6)
/G7: U1.72 (IO2_72), U2.10 (G7)
/R0: U1.91 (IO2_91), U2.41 (R0)
/R1: U1.89 (IO2_89), U2.42 (R1)
/R2: U1.87 (IO2_87), U2.43 (R2)
/R3: U1.86 (IO2_86), U2.44 (R3)
/R4: U1.85 (IO2_85), U2.45 (R4)
/R5: U1.84 (IO2_84), U2.46 (R5)
/R6: U1.83 (IO2_83), U2.47 (R6)
/R7: U1.82 (IO2_82), U2.48 (R7)
/RST_cpld: RN12.8 (R1.2), U1.6 (IO1_6)
/VCLK_ADV: U1.54 (IO2_54), U2.24 (VCLK)
/VCLK_cpld: RN12.6 (R3.2), U1.12 (IO1_12/GCLK0)
/VIDeBlur_t: J11.1 (A), U1.48 (IO1_48)
/en_IGR_DeBl_15b_Func: J12.1 (A), U1.50 (IO1_50)
/en_IGR_Rst_Func: J12.3 (B), U1.49 (IO1_49)
/~15b_mode_t: J11.3 (B), U1.47 (IO1_47)
/~BLANK: U1.71 (IO2_71), U2.11 (#BLANK)
/~CSYNC_75_pre: J31.1 (A), R31.2, R32.1, U3.1 (IN)
/~CSYNC: R13.2, R31.1, U1.98 (IO2_98)
/~SYNC: U1.70 (IO2_70), U2.12 (#SYNC)
/~SoG: J21.1 (A), U1.69 (IO2_69)
B_o: P_B1.1, RN23.4 (R4.1), U2.28 (IOB)
CTRL_i: P_CTRL1.1, RN12.2 (R2.1)
D0_i: P_D0.1, RN10.3 (R3.1)
D1_i: P_D1.1, RN10.2 (R2.1)
D2_i: P_D2.1, RN10.1 (R1.1)
D3_i: P_D3.1, RN11.4 (R4.1)
D4_i: P_D4.1, RN11.3 (R3.1)
D5_i: P_D5.1, RN11.2 (R2.1)
D6_i: P_D6.1, RN11.1 (R1.1)
DSYNC_i: P_DSYNC1.1, RN12.4 (R4.1)
Filter_Bypass: J2.2 (B), P_F1.1, P_F2.1, R2.1, U1.92 (IO2_92)
GND: C4.2, C5.2, C6.2, C17.2, C18.2, C19.2, C20.2, C21.2, C22.2, C23.2, C24.2, C25.2, C31.2, C32.2, C51.2, C52.2, FB4.1, FB5.1, J21.2 (B), P_GND_2.1, P_GND_3.1, P_GND_4.1, R2.2, R21.2, R32.2, R33.2, RN23.3 (R3.1), RN23.5 (R4.2), RN23.8 (R1.2), U1.1 (IO2_1), U1.60 (GNDIO), U1.62 (IO2_62/GCLK2), U1.64 (IO2_64/GCLK3), U1.79 (GNDIO), U1.93 (GNDIO), U1.95 (IO2_95), U2.1 (GND), U2.2 (GND), U2.14 (GND), U2.15 (GND), U2.25 (GND), U2.26 (GND), U2.27 (#IOB), U2.31 (#IOG), U2.33 (#IOR), U2.39 (GND), U2.40 (GND), U3.2 (GND), U5.2 (GND)
GNDD: C1.2, C2.2, C3.2, C10.2, C11.2, C12.2, C13.2, C14.2, C15.2, C16.2, C41.2, C42.2, FB4.2, FB5.2, J3.2, J3.10, J3b1.2, J3b1.10, J11.2 (C), J12.2 (C), P_GND_0.1, P_GND_1.1, R10.1, SHIELD_FINGER1.1, U1.8 (IO1_8), U1.10 (GNDIO), U1.11 (GNDINT), U1.32 (GNDIO), U1.37 (GNDINT), U1.46 (GNDIO), U1.65 (GNDINT), U1.90 (GNDINT), U4.2 (GND)
G_o: P_G1.1, RN23.2 (R2.1), RN23.6 (R3.2), RN23.7 (R2.2), U2.32 (IOG)
unnamed: C1.1, FB1.2, P_3V3.1
unnamed: C4.1, FB2.2, P_5V1.1
unnamed: C27.1, U2.36 (VREF)
unnamed: C28.1, U2.35 (COMP)
unnamed: J31.2 (B), R33.1
unnamed: R21.1, U2.37 (RSET)
unnamed: R22.2, U2.38 (#PSAVE)
unnamed: C33.2, C34.2, R34.2
unnamed: C34.1, U3.3 (SAG)
unnamed: C33.1, U3.4 (OUT)
RST_io: P_RST1.1, RN12.1 (R1.1)
R_o: P_R1.1, RN23.1 (R1.1), U2.34 (IOR)
TCK: J3.1, J3b1.1, R10.2, U1.24 (TCK)
TDI: J3.9, J3b1.9, R12.2, U1.23 (TDI)
TDO: J3.3, J3b1.3, U1.25 (TDO)
TMS: J3.5, J3b1.5, R11.2, U1.22 (TMS)
VCLK_i: P_VCLK1.1, RN12.3 (R3.1)
~CSYNC_75_o: P_CS_75.1, R34.1
~CSYNC_LVTTL_o: P_CS1.1, R13.1

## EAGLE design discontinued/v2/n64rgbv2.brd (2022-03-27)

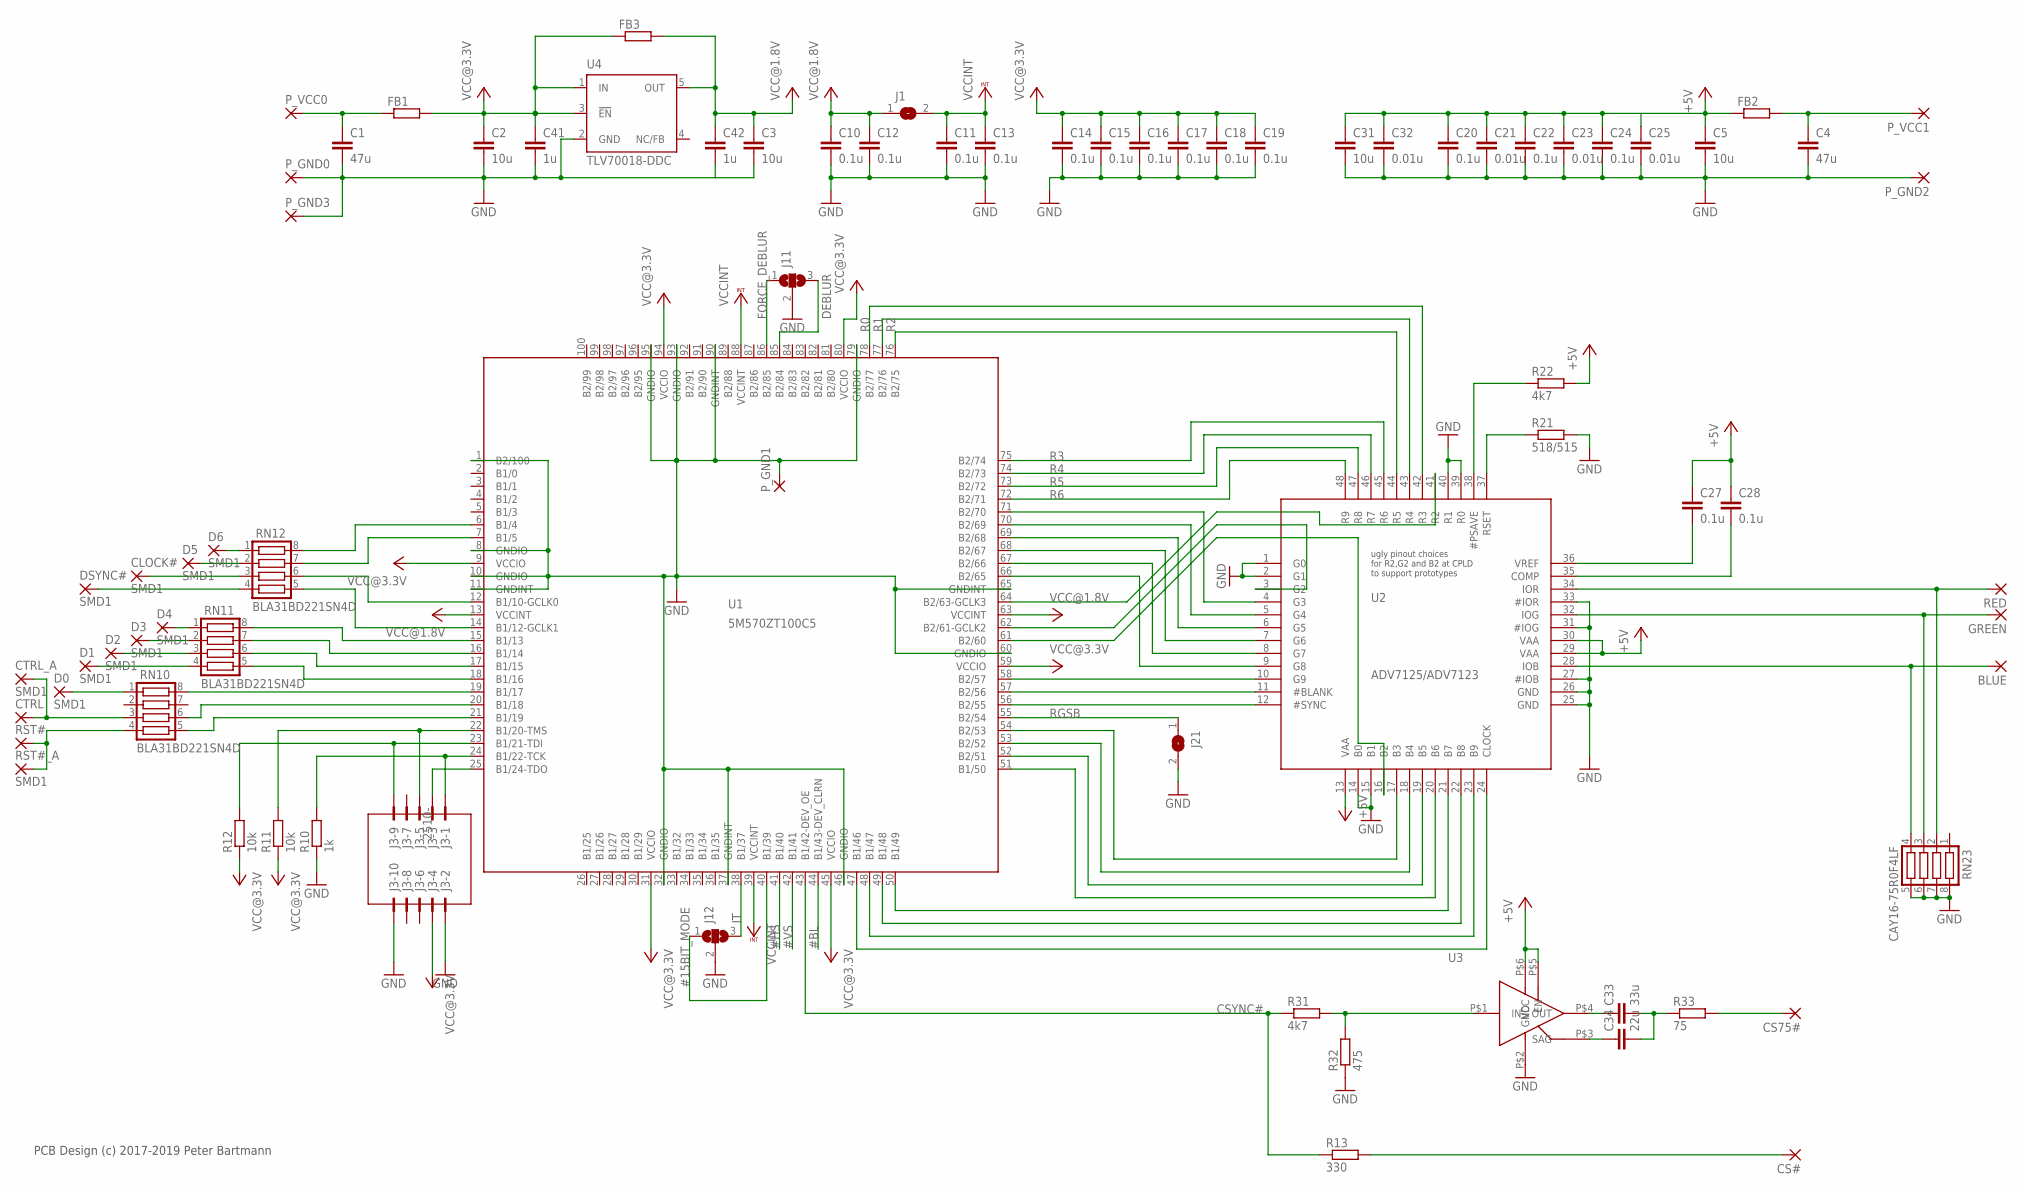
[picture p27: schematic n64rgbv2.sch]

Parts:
BLUE: SMD2; SMD1,27-2,54
C1, C4: 47u; C0805
C2, C3, C5, C31: 10u; C0805
C10, C11, C12, C13, C14, C15, C16, C17, C18, C19, C20, C22, C24, C27, C28: 0.1u; C0603
C21, C23, C25, C32: 0.01u; C0603
C33: 33u; C1210
C34: 22u; C1206
C41, C42: 1u; C0603
CLOCK#: SMD1; SMD0,8-1,6
CS75#: SMD2; SMD1,27-2,54
CS#: SMD2; SMD1,27-2,54
CTRL: SMD2; SMD1,27-2,54
CTRL_A: SMD1; SMD0,8-1,6
D0, D1, D2, D3, D4, D5, D6: SMD1; SMD0,8-1,6
DSYNC#: SMD1; SMD0,8-1,6
FB1, FB2, FB3: R-EU_R0603; R0603
GREEN: SMD2; SMD1,27-2,54
J1, J21: SJ
J3: 2510-; PAK100/2500-10
J11, J12: SJ2W; SJ_2
P_GND0, P_GND1, P_GND2, P_GND3: SMD2; SMD1,27-2,54
P_VCC0, P_VCC1: SMD2; SMD1,27-2,54
R10: 1k; R0603
R11, R12: 10k; R0603
R13: 330; R0603
R21: 518/515; R0603
R22, R31: 4k7; R0603
R32: 475; R0603
R33: 75; R0603
RED: SMD2; SMD1,27-2,54
RN10, RN11, RN12: BLA31BD221SN4D; CTS742C083
RN23: CAY16-75R0F4LF; CTS742C083
RST#: SMD2; SMD1,27-2,54
RST#_A: SMD1; SMD0,8-1,6
U1: 5M570ZT100C5; TQFP100
U2: ADV7125/ADV7123; LQFP48
U3: TSH122ICT; SC70
U4: TLV70018-DDC; SOT23-DBV

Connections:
#15BIT_MODE: J12.1, U1.40 (B1/39)
#BL: U1.44 (B1/43-DEV_CLRN)
#HS: U1.41 (B1/40)
#VS: U1.42 (B1/41)
+5V: C5.1, C20.1, C21.1, C22.1, C23.1, C24.1, C25.1, C27.1, C28.1, C31.1, C32.1, FB2.1, R22.2, U2.13 (VAA), U2.29 (VAA), U2.30 (VAA), U3.P$5 (EN), U3.P$6 (VCC)
BLUE: BLUE.1, RN23.4, U2.28 (IOB)
CSYNC#: R13.1, R31.1, U1.43 (B1/42-DEV_OE)
DEBLUR: J11.3, U1.85 (B2/84)
FORCE_DEBLUR: J11.1, U1.86 (B2/85)
GND: C1.2, C2.2, C3.2, C4.2, C5.2, C10.2, C11.2, C12.2, C13.2, C14.2, C15.2, C16.2, C17.2, C18.2, C19.2, C20.2, C21.2, C22.2, C23.2, C24.2, C25.2, C31.2, C32.2, C41.2, C42.2, J3.2, J3.10, J11.2, J12.2, J21.2, P_GND0.1, P_GND1.1, P_GND2.1, P_GND3.1, R10.1, R21.2, R32.1, RN23.5, RN23.6, RN23.7, RN23.8, U1.1 (B2/100), U1.8 (GNDIO), U1.10 (GNDIO), U1.11 (GNDINT), U1.32 (GNDIO), U1.37 (GNDINT), U1.46 (GNDIO), U1.60 (GNDIO), U1.65 (GNDINT), U1.79 (GNDIO), U1.90 (GNDINT), U1.93 (GNDIO), U1.95 (GNDIO), U2.1 (G0), U2.2 (G1), U2.14 (B0), U2.15 (B1), U2.25 (GND), U2.26 (GND), U2.27 (#IOB), U2.31 (#IOG), U2.33 (#IOR), U2.39 (R0), U2.40 (R1), U3.P$2 (GND), U4.2 (GND)
GREEN: GREEN.1, RN23.3, U2.32 (IOG)
IT: J12.3, U1.38 (B1/37)
unnamed: D6.P$1, RN12.1
unnamed: D5.P$1, RN12.2
unnamed: DSYNC#.P$1, RN12.4
unnamed: CLOCK#.P$1, RN12.3
unnamed: RN10.4, RST#.1, RST#_A.P$1
unnamed: CTRL.1, CTRL_A.P$1, RN10.3
unnamed: D0.P$1, RN10.1
unnamed: RN10.8, U1.19 (B1/17)
unnamed: RN10.6, U1.20 (B1/18)
unnamed: RN10.5, U1.21 (B1/19)
unnamed: RN11.5, U1.18 (B1/16)
unnamed: RN11.6, U1.17 (B1/15)
unnamed: CS#.1, R13.2
unnamed: RN11.7, U1.16 (B1/14)
unnamed: RN11.8, U1.15 (B1/13)
unnamed: D1.P$1, RN11.4
unnamed: D2.P$1, RN11.3
unnamed: D3.P$1, RN11.2
unnamed: D4.P$1, RN11.1
unnamed: RN12.7, U1.7 (B1/5)
unnamed: RN12.8, U1.6 (B1/4)
unnamed: RN12.5, U1.14 (B1/12-GCLK1)
unnamed: RN12.6, U1.12 (B1/10-GCLK0)
unnamed: U1.71 (B2/70), U2.4 (G3)
unnamed: U1.64 (B2/63-GCLK3), U2.41 (R2)
unnamed: U1.70 (B2/69), U2.5 (G4)
unnamed: U1.69 (B2/68), U2.6 (G5)
unnamed: U1.68 (B2/67), U2.7 (G6)
unnamed: U1.67 (B2/66), U2.8 (G7)
unnamed: U1.66 (B2/65), U2.9 (G8)
unnamed: U1.58 (B2/57), U2.10 (G9)
unnamed: U1.56 (B2/55), U2.12 (#SYNC)
unnamed: U1.47 (B1/46), U2.24 (CLOCK)
unnamed: U1.48 (B1/47), U2.23 (B9)
unnamed: U1.49 (B1/48), U2.22 (B8)
unnamed: U1.50 (B1/49), U2.21 (B7)
unnamed: U1.51 (B1/50), U2.20 (B6)
unnamed: U1.52 (B2/51), U2.19 (B5)
unnamed: U1.53 (B2/52), U2.18 (B4)
unnamed: U1.54 (B2/53), U2.17 (B3)
unnamed: U1.62 (B2/61-GCLK2), U2.3 (G2)
unnamed: U1.57 (B2/56), U2.11 (#BLANK)
unnamed: U1.61 (B2/60), U2.16 (B2)
unnamed: C4.1, FB2.2, P_VCC1.1
unnamed: C1.1, FB1.1, P_VCC0.1
unnamed: C33.2, C34.2, R33.1
unnamed: CS75#.1, R33.2
unnamed: C33.1, U3.P$4 (OUT)
unnamed: C34.1, U3.P$3 (SAG)
unnamed: R21.1, U2.37 (RSET)
unnamed: R22.1, U2.38 (#PSAVE)
unnamed: C28.2, U2.35 (COMP)
unnamed: R31.2, R32.2, U3.P$1 (IN)
unnamed: C27.2, U2.36 (VREF)
R0: U1.78 (B2/77), U2.42 (R3)
R1: U1.77 (B2/76), U2.43 (R4)
R2: U1.76 (B2/75), U2.44 (R5)
R3: U1.75 (B2/74), U2.45 (R6)
R4: U1.74 (B2/73), U2.46 (R7)
R5: U1.73 (B2/72), U2.47 (R8)
R6: U1.72 (B2/71), U2.48 (R9)
RED: RED.1, RN23.2, U2.34 (IOR)
RGSB: J21.1, U1.55 (B2/54)
TCK: J3.1, R10.2, U1.24 (B1/22-TCK)
TDI: J3.9, R12.2, U1.23 (B1/21-TDI)
TDO: J3.3, U1.25 (B1/24-TDO)
TMS: J3.5, R11.2, U1.22 (B1/20-TMS)
VCC@1.8V: C3.1, C10.1, C12.1, C42.1, FB3.2, J1.1, U1.13 (VCCINT), U1.63 (VCCINT), U4.5 (OUT)
VCC@3.3V: C2.1, C14.1, C15.1, C16.1, C17.1, C18.1, C19.1, C41.1, FB1.2, FB3.1, J3.4, R11.1, R12.1, U1.9 (VCCIO), U1.31 (VCCIO), U1.45 (VCCIO), U1.59 (VCCIO), U1.80 (VCCIO), U1.94 (VCCIO), U4.1 (IN), U4.3 (!EN)
VCCINT: C11.1, C13.1, J1.2, U1.39 (VCCINT), U1.88 (VCCINT)

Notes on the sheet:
ugly pinout choices for R2,G2 and B2 at CPLD to support prototypes
PCB Design (c) 2017-2019 Peter Bartmann

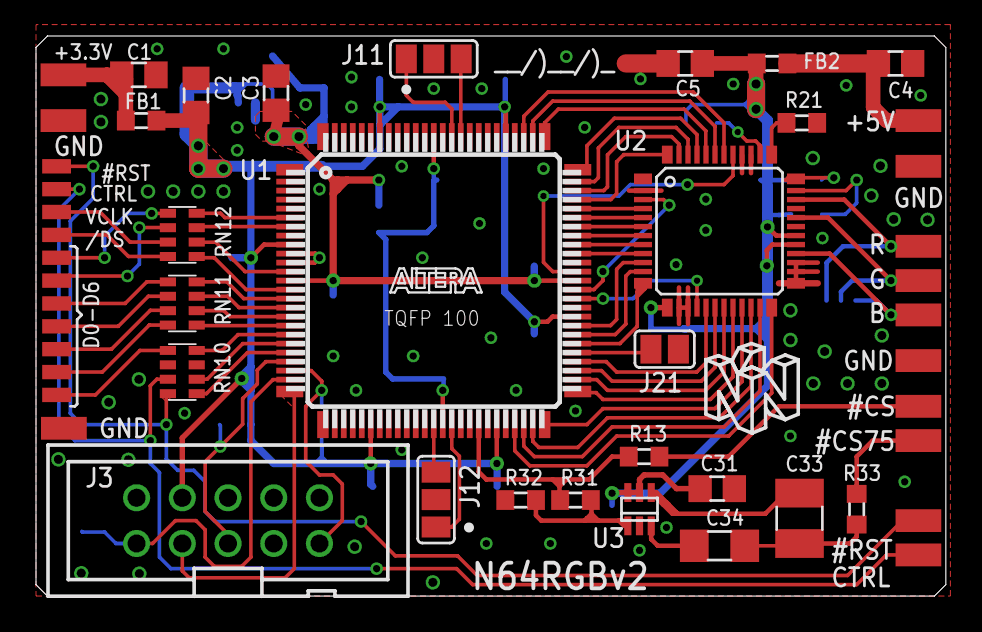
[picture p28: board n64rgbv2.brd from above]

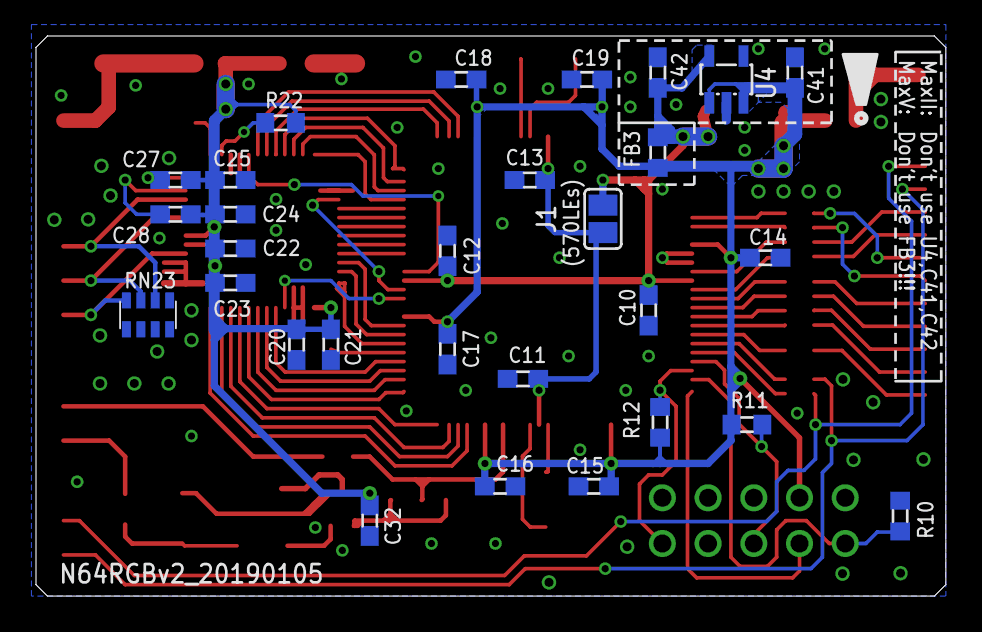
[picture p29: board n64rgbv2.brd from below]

Board: 2 copper layers, 50.5 x 31.1 mm, 78 parts (29 on the bottom side), 79 nets.

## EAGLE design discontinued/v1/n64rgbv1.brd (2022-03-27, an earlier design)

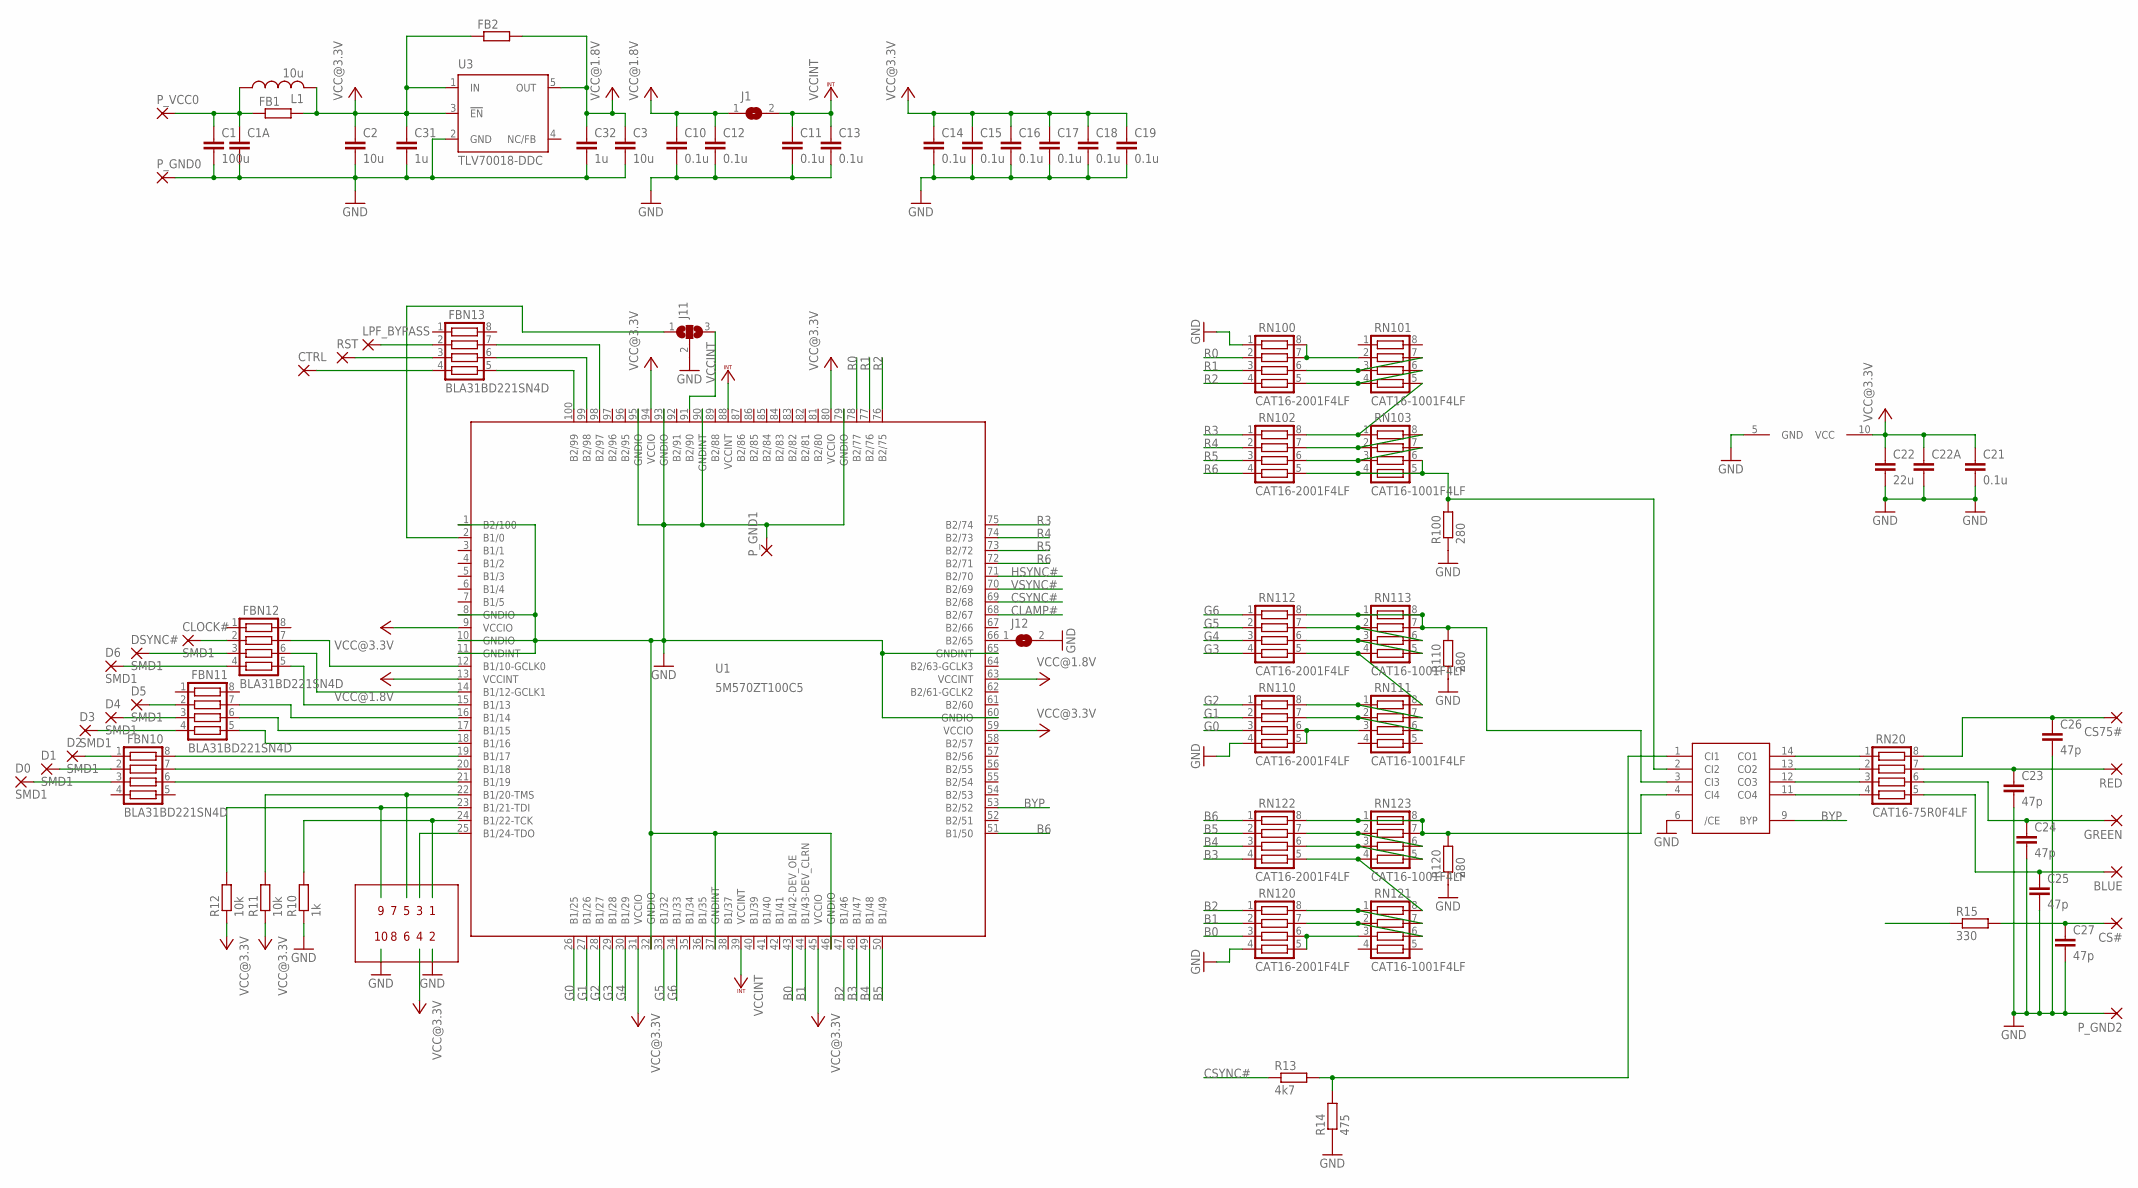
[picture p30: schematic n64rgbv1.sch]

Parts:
BLUE: SMD2; SMD1,27-2,54
C1: 100u; C1206K
C1A, C22A: C-EUC0805; C0805
C2, C3: 10u; C0805
C10, C11, C12, C13, C14, C15, C16, C17, C18, C19, C21: 0.1u; C0603
C22: 22u; C1206K
C23, C24, C25, C26, C27: 47p; C0603
C31, C32: 1u; C0603
CLOCK#: SMD1; SMD0,8-1,6
CS75#: SMD2; SMD1,27-2,54
CS#: SMD2; SMD1,27-2,54
CTRL: SMD2; SMD1,27-2,54
D0, D1, D2, D3, D4, D5, D6: SMD1; SMD0,8-1,6
DSYNC#: SMD1; SMD0,8-1,6
FB1, FB2: R-EU_R0603; R0603
FBN10, FBN11, FBN12, FBN13: BLA31BD221SN4D; CTS742C083
GREEN: SMD2; SMD1,27-2,54
J1, J12: SJ
J11: SJ2W; SJ_2
L1: 10u; L3230M
LPF_BYPASS: SMD2; SMD1,27-2,54
P_GND0, P_GND1, P_GND2: SMD2; SMD1,27-2,54
P_VCC0: SMD2; SMD1,27-2,54
R10: 1k; R0603
R11, R12: 10k; R0603
R13: 4k7; R0603
R14: 475; R0603
R15: 330; R0603
R100, R110, R120: 280; R0603
RED: SMD2; SMD1,27-2,54
RN20: CAT16-75R0F4LF; CTS742C083
RN100, RN102, RN110, RN112, RN120, RN122: CAT16-2001F4LF; CTS742C083
RN101, RN103, RN111, RN113, RN121, RN123: CAT16-1001F4LF; CTS742C083
RST: SMD2; SMD1,27-2,54
U1: 5M570ZT100C5; TQFP100
U2: THS7374
U3: TLV70018-DDC; SOT23-DBV

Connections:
B0: RN120.3, U1.43 (B1/42-DEV_OE)
B1: RN120.2, U1.44 (B1/43-DEV_CLRN)
B2: RN120.1, U1.47 (B1/46)
B3: RN122.4, U1.48 (B1/47)
B4: RN122.3, U1.49 (B1/48)
B5: RN122.2, U1.50 (B1/49)
B6: RN122.1, U1.51 (B1/50)
BYP: U1.53 (B2/52), U2.9 (BYP)
CLAMP#: U1.68 (B2/67)
CSYNC#: R13.1, R15.1, U1.69 (B2/68)
G0: RN110.3, U1.26 (B1/25)
G1: RN110.2, U1.27 (B1/26)
G2: RN110.1, U1.28 (B1/27)
G3: RN112.4, U1.29 (B1/28)
G4: RN112.3, U1.30 (B1/29)
G5: RN112.2, U1.33 (B1/32)
G6: RN112.1, U1.34 (B1/33)
GND: C1.2, C1A.2, C2.2, C3.2, C10.2, C11.2, C12.2, C13.2, C14.2, C15.2, C16.2, C17.2, C18.2, C19.2, C21.2, C22.2, C22A.2, C23.2, C24.2, C25.2, C26.2, C27.2, C31.2, C32.2, J11.2, J12.2, P_GND0.1, P_GND1.1, P_GND2.1, R10.1, R14.1, R100.1, R110.1, R120.1, RN100.1, RN110.4, RN120.4, U1.1 (B2/100), U1.8 (GNDIO), U1.10 (GNDIO), U1.11 (GNDINT), U1.32 (GNDIO), U1.37 (GNDINT), U1.46 (GNDIO), U1.60 (GNDIO), U1.65 (GNDINT), U1.79 (GNDIO), U1.90 (GNDINT), U1.93 (GNDIO), U1.95 (GNDIO), U2.5 (GND), U2.6 (/CE), U3.2 (GND)
HSYNC#: U1.71 (B2/70)
unnamed: R13.2, R14.2, U2.1 (CI1)
unnamed: C23.1, RED.1, RN20.7
unnamed: RN20.1, U2.14 (CO1)
unnamed: RN20.2, U2.13 (CO2)
unnamed: RN20.3, U2.12 (CO3)
unnamed: RN20.4, U2.11 (CO4)
unnamed: CTRL.1, FBN13.4
unnamed: FBN13.3, RST.1
unnamed: FBN13.2, LPF_BYPASS.1
unnamed: C24.1, GREEN.1, RN20.6
unnamed: BLUE.1, C25.1, RN20.5
unnamed: C26.1, CS75#.1, RN20.8
unnamed: C27.1, CS#.1, R15.2
unnamed: FBN13.5, U1.100 (B2/99)
unnamed: D1.P$1, FBN10.2
unnamed: D0.P$1, FBN10.3
unnamed: D2.P$1, FBN10.1
unnamed: FBN10.6, U1.21 (B1/19)
unnamed: FBN10.7, U1.20 (B1/18)
unnamed: FBN10.8, U1.19 (B1/17)
unnamed: D3.P$1, FBN11.4
unnamed: D4.P$1, FBN11.3
unnamed: D5.P$1, FBN11.2
unnamed: D6.P$1, FBN12.4
unnamed: RN110.5, RN110.6, RN111.3
unnamed: RN110.7, RN111.2, RN111.6
unnamed: RN110.8, RN111.1, RN111.7
unnamed: RN111.8, RN112.5, RN113.4
unnamed: RN112.6, RN113.3, RN113.5
unnamed: RN112.7, RN113.2, RN113.6
unnamed: R120.2, RN122.8, RN123.1, RN123.7, RN123.8, U2.4 (CI4)
unnamed: RN120.5, RN120.6, RN121.3
unnamed: RN120.7, RN121.2, RN121.6
unnamed: RN120.8, RN121.1, RN121.7
unnamed: RN121.8, RN122.5, RN123.4
unnamed: DSYNC#.P$1, FBN12.3
unnamed: RN122.6, RN123.3, RN123.5
unnamed: RN122.7, RN123.2, RN123.6
unnamed: CLOCK#.P$1, FBN12.2
unnamed: FBN11.5, U1.18 (B1/16)
unnamed: FBN11.6, U1.17 (B1/15)
unnamed: FBN11.7, U1.16 (B1/14)
unnamed: FBN12.5, U1.15 (B1/13)
unnamed: FBN12.6, U1.14 (B1/12-GCLK1)
unnamed: FBN12.7, U1.12 (B1/10-GCLK0)
unnamed: FBN13.6, U1.99 (B2/98)
unnamed: FBN13.7, U1.98 (B2/97)
unnamed: R100.2, RN102.5, RN103.4, RN103.5, RN103.6, U2.2 (CI2)
unnamed: J12.1, U1.66 (B2/65)
unnamed: J11.3, U1.91 (B2/90)
unnamed: J11.1, U1.2 (B1/0)
unnamed: C1.1, C1A.1, FB1.1, L1.1, P_VCC0.1
unnamed: R110.2, RN112.8, RN113.1, RN113.7, RN113.8, U2.3 (CI3)
unnamed: RN100.7, RN100.8, RN101.2
unnamed: RN100.6, RN101.3, RN101.7
unnamed: RN100.5, RN101.4, RN101.6
unnamed: RN101.5, RN102.8, RN103.1
unnamed: RN102.7, RN103.2, RN103.8
unnamed: RN102.6, RN103.3, RN103.7
R0: RN100.2, U1.78 (B2/77)
R1: RN100.3, U1.77 (B2/76)
R2: RN100.4, U1.76 (B2/75)
R3: RN102.1, U1.75 (B2/74)
R4: RN102.2, U1.74 (B2/73)
R5: RN102.3, U1.73 (B2/72)
R6: RN102.4, U1.72 (B2/71)
TCK: R10.2, U1.24 (B1/22-TCK)
TDI: R12.2, U1.23 (B1/21-TDI)
TDO: U1.25 (B1/24-TDO)
TMS: R11.2, U1.22 (B1/20-TMS)
VCC@1.8V: C3.1, C10.1, C12.1, C32.1, FB2.2, J1.1, U1.13 (VCCINT), U1.63 (VCCINT), U3.5 (OUT)
VCC@3.3V: C2.1, C14.1, C15.1, C16.1, C17.1, C18.1, C19.1, C21.1, C22.1, C22A.1, C31.1, FB1.2, FB2.1, L1.2, R11.1, R12.1, U1.9 (VCCIO), U1.31 (VCCIO), U1.45 (VCCIO), U1.59 (VCCIO), U1.80 (VCCIO), U1.94 (VCCIO), U2.10 (VCC), U3.1 (IN), U3.3 (!EN)
VCCINT: C11.1, C13.1, J1.2, U1.39 (VCCINT), U1.88 (VCCINT)
VSYNC#: U1.70 (B2/69)

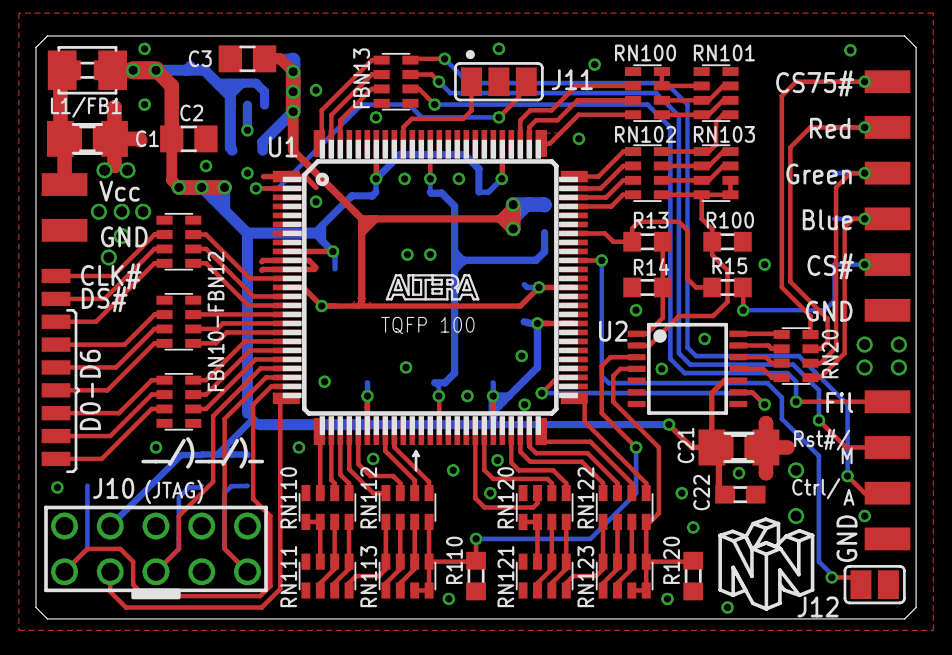
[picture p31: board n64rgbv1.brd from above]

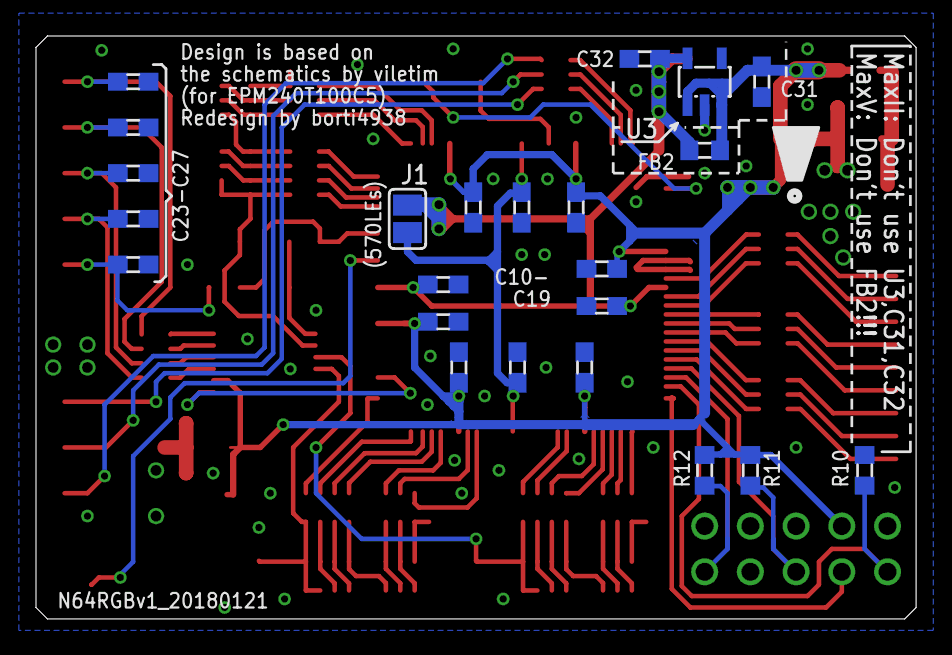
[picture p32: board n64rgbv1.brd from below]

Board: 2 copper layers, 48.9 x 32.4 mm, 80 parts (23 on the bottom side), 89 nets.

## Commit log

2022-03-27 add table of contents and a remark on MaxII and MaxV assembly differences
2022-07-13 misc updates: - update KiCad to v6 - add SMD footprint for JTAG connector
    [BOM_n64rgbv2.1.xlsx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]
